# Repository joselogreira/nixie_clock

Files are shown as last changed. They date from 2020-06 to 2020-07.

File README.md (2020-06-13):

# **The Nixie Tube Clock** by [Nuvitron]

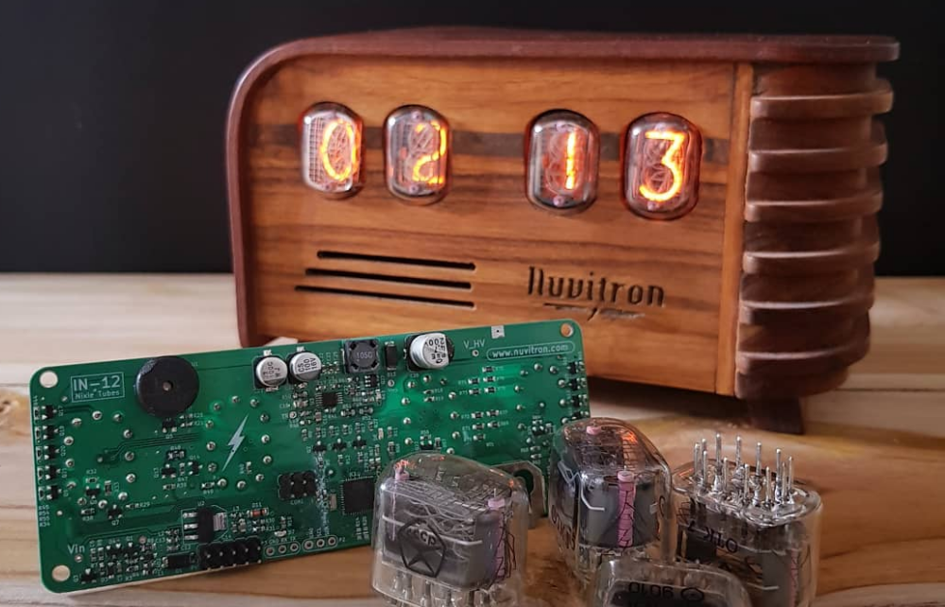
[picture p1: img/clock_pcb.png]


At Nuvitron, I led the electronics development of The Nixie Clock hardware included in some of their models. This repository starts from the production version of the clock circuit, and includes further improvements in the form of:

- Code refactoring
- Hardware tweaks (pending)

---

## Toolchain:

This project is based on an [ATmega324pb][324pb] MCU from Atmel (now Microchip). The standard AVR toolchain for Ubuntu Linux was used. No bootloader implemented. Not tested under Windows or Mac.

- [avr-gcc] for compiling and building.
- [avr-libc] for AVR libraries.
- [avrdude] for programming, using [usbasp] programmer or alternatively the official [AVR ISP MK2][mk2]

There're many guides on how to install and set-up the toolchain. [Here's one] of many guides available.

***Sidenote:*** The ATmega324pb MCU is NOT supported by default, neither by *AVRdude* nor by *avr-gcc*, thus, a few extra steps need to be performed in order to get this toolchain to work properly. It's just a matter of including some extra files in the proper locatios to fully support the MCU:
* **AVRdude**: it uses a configuration file that includes all MCUs recognized by the program, among other things. Mine is at `/etc/avrdude.conf`. Edit it (with *root* proviledges) and add an entry for the *ATmega324pb*. Use the *ATmega324pa* as an example, which inherits most of the properties from the ATmega324p. The signature for the 324pb is `1e 95 17`. Alternatively, I've added my `avrdude.conf` to the repo, [here][special].
* **avr-gcc**: A device specification file must be included. My path: `/usr/lib/gcc/avr/5.4.0/device-spec/`. The missing file is called `specs-atmega324pb` and I found it in a Windows installation of [Atmel Studio][astudio], the Atmel IDE for Windows. Within this file there's a couple of dependencies pointing to files in the avr-libc path.
* **avr-libc**: Three files are needed. Again, I found them in the Atmel Studio Windows installation path. My paths for these files are:
  * `/usr/lib/avr/include/avr/` must include the file `iom324pb.h`, which is the memory mapping for all MCU peripherals and special registers.
  * `/usr/lib/avr/lib/avr5/` must include `crtatmega324pb.o` and `libatmega324pb.a`.

***Sidenote 2:*** The latest version of Atmel Studio (7.0, at the time of this writting) doesn't include support for the *ATmega324pb* out-of-the-box. Instead, the user must install an additional package to fully support it. It's called *"Device Firmware Pack"*, and it's installed within Atmel Studio in the *"Device Package Manager"* window. Search for ATmega_DFP and install it. Mine was version `1.2.272`. Once installed, the previously mentioned Windows files can be found at:
  * `\<install-path>\Atmel\Studio\7.0\packs\atmel\ATmega_DFP\1.2.272\include\avr\iom324pb.h`
  * `\<install-path>\Atmel\Studio\7.0\packs\atmel\ATmega_DFP\1.2.272\gcc\dev\atmega324pb\avr5\crtatmega324pb.o` and `libatmega324pb.a`
  * `\<install-path>\Atmel\Studio\7.0\packs\atmel\ATmega_DFP\1.2.272\gcc\dev\atmega324pb\device-specs\specs-atmega324pb`

For the sake of completeness, these files are also included [here][special].

---

## Project Folders
- **src**: contains all the code files needed, including library files.
- **special**: contains all *"additional"* files to support the MCU.
- **img**: some images of the project.
- **docs**: GitHub [project page][ppage].
- **output**: not included in the repo. Automatically created once the Make recipe is executed.

---

## Hardware Characteristics:
- MCU: ATmega324pb 
- (pending)

---

## License

Released under the [MIT License][license] - 2020 Jose Logreira

[clock_pcb]: https://raw.githubusercontent.com/joselogreira/nixie_clock/master/img/clock_pcb.png "Nixie Clock Circuit"
[Nuvitron]: <https://nuvitron.com>
[avr-gcc]: <https://www.microchip.com/mplab/avr-support/avr-and-arm-toolchains-c-compilers>
[avr-libc]: <https://www.nongnu.org/avr-libc/user-manual/overview.html>
[avrdude]: <https://www.nongnu.org/avrdude/>
[usbasp]: <https://www.fischl.de/usbasp/>
[Here's one]: <http://maxembedded.com/2015/06/setting-up-avr-gcc-toolchain-on-linux-and-mac-os-x/>
[special]: /special/
[astudio]: https://www.microchip.com/mplab/avr-support/atmel-studio-7
[324pb]: http://ww1.microchip.com/downloads/en/DeviceDoc/40001908A.pdf
[mk2]: http://ww1.microchip.com/downloads/en/DeviceDoc/Atmel-42093-AVR-ISP-mkII_UserGuide.pdf
[license]: /LICENSE
[ppage]: https://joselogreira.github.io/nixie_clock/

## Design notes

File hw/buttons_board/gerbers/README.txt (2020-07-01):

Description of the compressed files:

PROJECT NAME: buttons_board
> THT components only
> Components in only top side of the PCB

Gerber files and description:

- buttons_board.drl: (Excellon) Descripción de las perforaciones de la tarjeta
- buttons_board-B.Cu.gbr: (Gerber) Máscara inferior de pistas de cobre
- buttons_board-B.Mask.gbr: (Gerber) Máscara inferior de puntos de soldadura de componentes 
- buttons_board-drl.rpt: (Texto Plano) Listado de diámetros de brocas a usar
- buttons_board-drl_map.gbr: (Gerber) Mapa de perforaciones en formato gerber
- buttons_board-Eco1.User.gbr: (Gerber) Capa de domentación para fabricación
- buttons_board-Edge.Cuts.gbr: (Gerber) Bordes de la PCB
- buttons_board-F.Silk.gbr: (Gerber) Máscara superior de componentes, Logo y leyendas

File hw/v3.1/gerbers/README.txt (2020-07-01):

Description of the compressed files:

PROJECT NAME: nixie_clock_3
> SMT and THT components 
> Components in both sides of the PCB

Gerber files and description:

- nixie_clock_3.drl: (Excellon) Description of the board drilling holes
- nixie_clock_3-B.Cu.gbr: (Gerber) Bottom mask of copper traces
- nixie_clock_3-B.Mask.gbr: (Gerber) Bottom mask of components solder paste layer
- nixie_clock_3-B.Silk.gbr: (Gerber) Bottom mask of components silkscreen and logos
- nixie_clock_3-drl.rpt: (Plain text) Drilling bit diameters list
- nixie_clock_3-drl_map.gbr: (Gerber) Map of drilling holes as gerber format
- nixie_clock_3-Eco1.User.gbr: (Gerber) Documentation layer for manufacturing
- nixie_clock_3-Edge.Cuts.gbr: (Gerber) PCB edges
- nixie_clock_3-F.Cu.gbr: (Gerber) Top mask of copper traces
- nixie_clock_3-F.Mask.gbr: (Gerber) Top mask of components solder paste layer
- nixie_clock_3-F.Silk.gbr: (Gerber) Top mask of components silkscreen and logos

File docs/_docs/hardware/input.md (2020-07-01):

---
title: Input protection
permalink: /docs/input/
---

__[PDF schematic](/nixie_clock/assets/pdf/nixie_clock_3.pdf "Schematic")__

The circuit is protected against four undesired situations:

* _Reverse polarity protection_
* _Overvoltage_
* _Undervoltage_
* _Inrush current_

The image below shows the power input circut section, that implements 3 of these four measures.

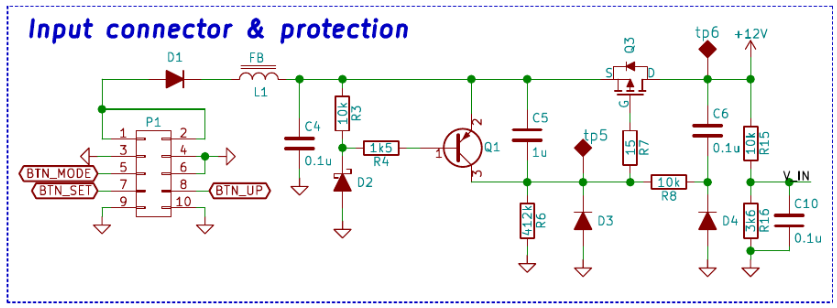
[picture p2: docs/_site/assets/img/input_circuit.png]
Input circuit


The connector P1 to the left receives power and button signals from a secondary PCB on the back of the clock that includes the 12V plug and three buttons. Both PCBs are connected via a 10-wire ribbon cable.

* ___Reverse polarity protection:___ This is the simplest. The diode `D1` protects against any backward current flow. The drawback is the diode voltage drop (close to 0.5V). If necessary, it can be avoided by using a MOSFET switch like [this one](https://circuitdigest.com/electronic-circuits/reverse-polarity-protection-circuit-diagram). But it wasn't necessary in this case.

* ___Overvoltage:___ `D2` is a Zener diode with zener voltage of 14V. When an input voltage above 14.5V (aprox.) is applied to the input, `D2` conducts current, forcing `Q1` into saturation (that is, Vce close to zero), thus, switching the P-channel MOSFET transistor `Q3` off. This way, overvoltage causes the whole circuit to be de-energized. Only the maximum voltage ratings of the input components limit the maximum input voltage, which can be up to 40V. Overvoltage protection is desired since some of the components of the circuit have a maximum voltage rating of 18V.

* ___Undervoltage:___ This one is not implemented by the input circuitry. There might be a discrete solution using zeners and transistors to implement undervoltage limits, but it was much easier to 
do in software. Basically, at start up, the MCU checks all system voltages. If there's an input voltage lower than nominal 12V, the boost converter won't be enabled. This way, the boost controller is protected from working with duty cicle very close to 1.

* ___Inrush current:___ Needed for two reasons:
	* The current spike produced in the connection process degrades the bulk capacitance in the circuit, and may produce MCU malfunction at start up.
	* The quality of the user's power adapter is unkwnown, and there's an alarmingly high amount of adapters without converter controller chips. This translates into power adapters not working, or producing big voltage sags in the connection moment, or outputting voltages different than 12V after connecting them. Thus, [Inrush Current Limitting](https://en.wikipedia.org/wiki/Inrush_current_limiter) (ICL) is a safety measure against weak power sources.

ICL is the most interesting, so it's explained below.

The goal is to switch on `Q3` slowly, in a controlled fashion, so that it remains in active mode (not in saturation) for a short period of time, such that it effectively acts as a resistor. This is achieved by slowly decreasing the Gate voltage (with respect to Source) using the RC  filter `C5` and `R6`. As soon as `Q3` reaches the threshold voltage, current starts flowing through the transistor and the voltage at `TP6` increases. `C6` and `R8` act as a feedback loop, so when voltage at `TP6` increases, current across `R6` also increases and _Vgs_ (source-gate voltage) gets regulated. The whole transient effect results in a very nice ramp voltage from zero to 12 volts at `TP6` (the +12V rail), lasting a some milliseconds. This is shown in the image below.

osciloscope capture

<ul>
	<li><strong style="color:gold">Yellow trace:</strong> Input voltage rail (from power adapter).</li>
	<li><strong style="color:aqua">Blue trace:</strong> MOSFET gate voltage (with respect to ground).</li>
	<li><strong style="color:purple">Purple trace:</strong> 12V rail (TP6).</li>
</ul>

`R15` and `R16` sample the input voltage to be read by the MCU.

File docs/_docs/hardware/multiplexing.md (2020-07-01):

---
title: Tubes' discrete multiplexing
permalink: /docs/multiplexing/
---

__[PDF schematic](/nixie_clock/assets/pdf/nixie_clock_3.pdf "Schematic")__

Multiplexing is mandatory. There's just not enough pins in the MCU to directly drive evey tube.

To multiplex tubes' anodes, [high side drivers](https://electronics.stackexchange.com/questions/188745/high-side-driver-and-low-side-driver) are needed. To multiplex tubes' digits (cathodes), low side drivers are needed.

At the time of sourcing the components, no integrated IC driver was found for 160V high side switching. It's just too much voltage, so a discrete solution was implemented using high voltage transistors. Every tube anode required a pair of NPN-PNP transistors. For the digits multiplexing, discrete high voltage transistors were used.

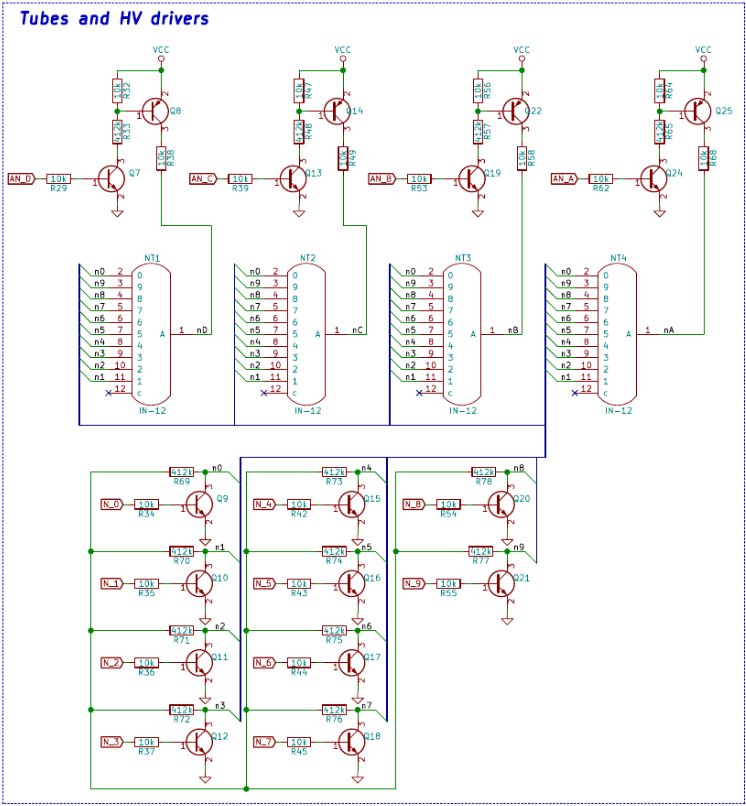
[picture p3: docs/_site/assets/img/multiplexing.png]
Tubes' multiplexing Tubes' Multiplexing


An interesting addition were the resistors `R69` to `R77`. They're all the same high value, and they all join each low side transistor's drain terminal (or cathode terminal) with a floating common node for all digits. Why is that? The concept was taken from the reference design below [found here](https://www.pinitech.com/retrofit/schematics.php).

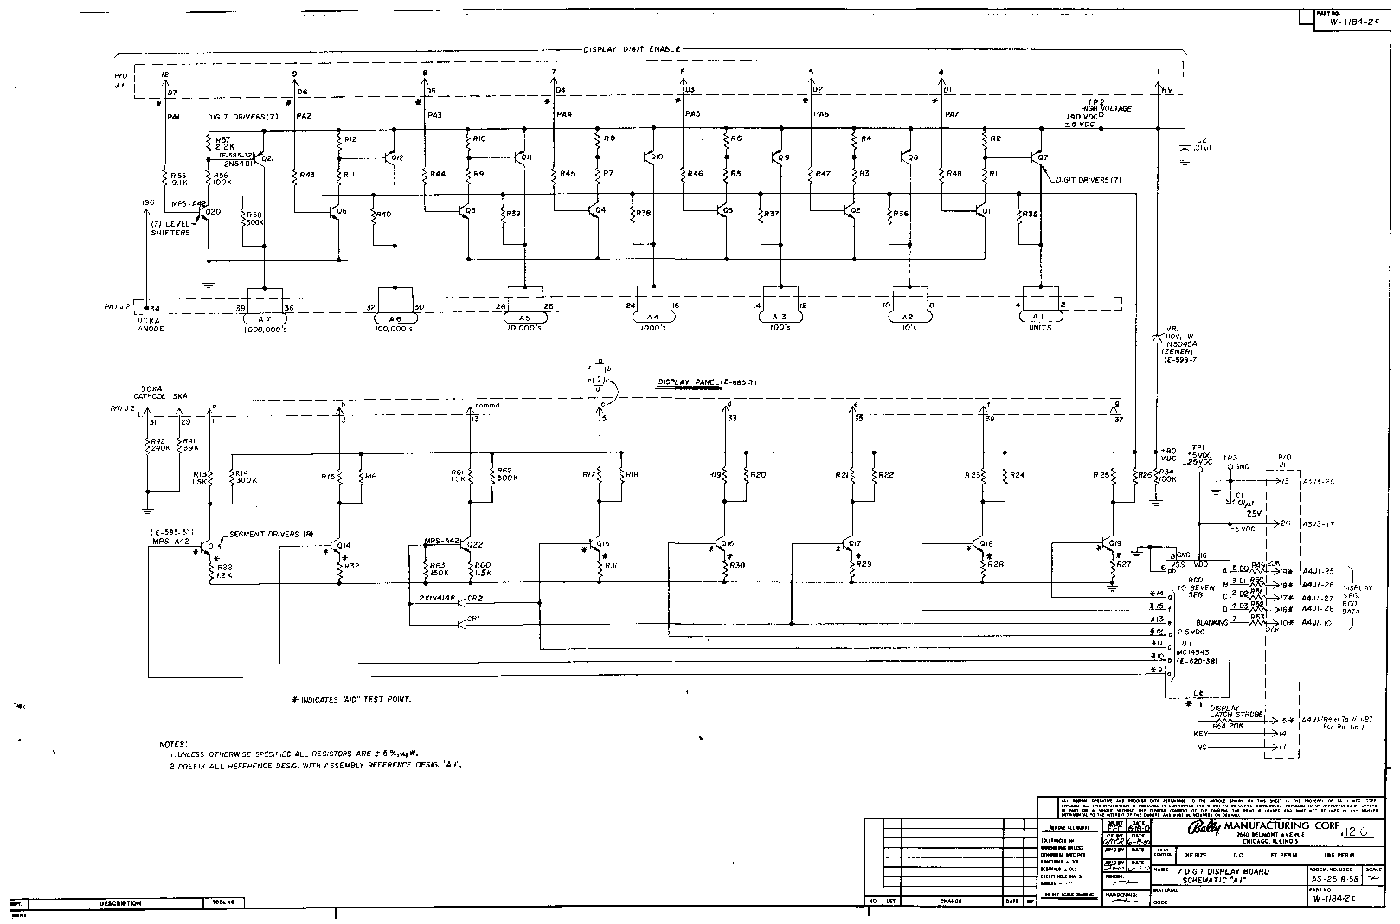
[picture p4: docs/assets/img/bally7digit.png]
bally7digit


Basically, __not all tubes' digits require the same voltage to glow__, thus, when multiplexing, it happens that one digit being addressed requires more anode-to-cathode voltage than others not being addressed, thus, the voltage applied to the one being addressed is enough to lightly make the one not being addressed glow, and the current flow goes throgh the low-side driver of the digit being addressed. This is because inside the tubes, no electrical isolation exists between the digits. This is the origin of the so-called ghosting effect in nixie tubes.

One solution is the one proposed: by tying all cathodes with high value resistors, only the addressed digit is fully ON, and all other cathodes are at a higher potential, that inhibits them from glowing. The solution is not perfect, but is simple and greatly reduces ghosting. Other solutions require more resistors, capacitors, zeners and the like, operating at high voltage, which requires way more space than what is available on the PCB (due to [clearance and creepage distances](https://www.smps.us/pcbtracespacing.html)).

## Timing

Each tube's anode is addressed for 5ms. During that time, the addressed tube's digit is ON for 1 to 5ms. It depends on the fade level. That way, individual fading levels can be applied to each tube. This is useful for implementing animations or transition effects.

Timing is completely controlled by ISRs. More on that, [here](/nixie_clock/docs/isr/).

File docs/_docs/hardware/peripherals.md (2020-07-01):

---
title: MCU peripherals
permalink: /docs/peripherals/
---

__[PDF schematic](/nixie_clock/assets/pdf/nixie_clock_3.pdf "Schematic")__

This is a list of the peripherals used:

* __GPIO__: including pin change interrupts
* __ADC__: to check system voltages.
* __EEPROM__: to save or read user configuration and testing results.
* __UART__: serial communication to communicate with PC
* __Timers__: events and tasks coordination. It includes RTC (using external quartz crystal) and LEDs' PWM generation.

Some of the miscellaneus elements around the MCU are shown below.

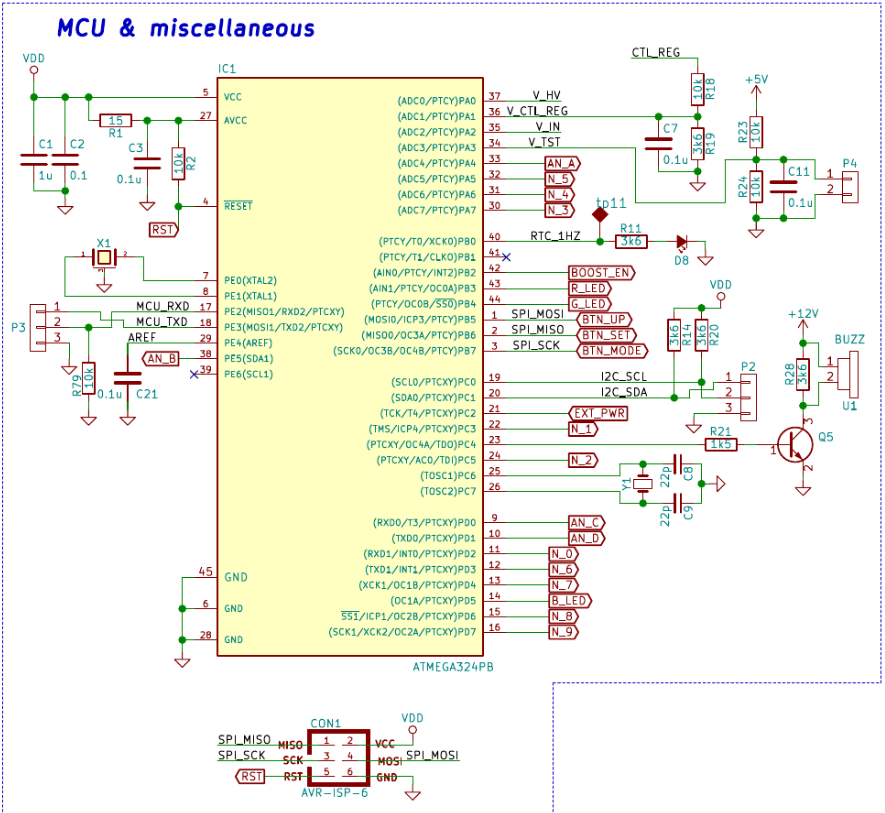
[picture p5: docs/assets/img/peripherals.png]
Peripherals Tubes' Multiplexing


The buzzer shown below is a piezoelectric one. Using a timer to generate 50% duty cycle PWM with variable frequency, different tones are generated.

Four RGB LEDs are mounted behind every tube. They are wired as two strings of LEDs. These are also controlled by PWM generated by timers with fixed frequency, but variable duty cycle.

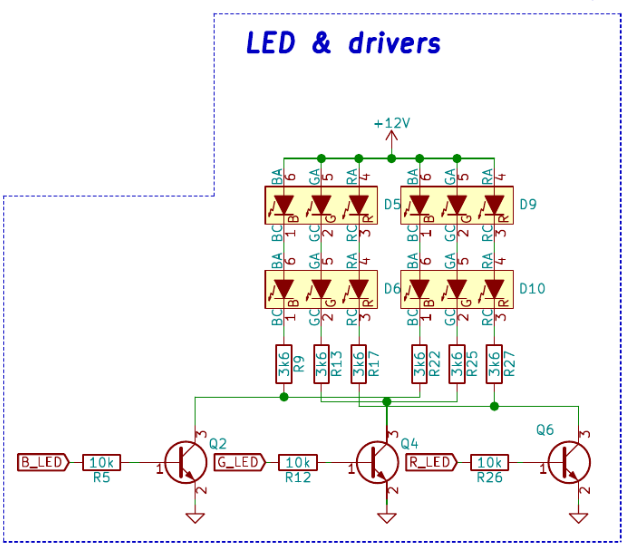
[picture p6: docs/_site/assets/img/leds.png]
LEDs strings


The I2C port was left available for any future addition or integration with I2C-based devices like temperature sensors, accelerometers, etc.

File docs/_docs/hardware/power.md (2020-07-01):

---
title: Voltages and power
permalink: /docs/power/
---

__[PDF schematic](/nixie_clock/assets/pdf/nixie_clock_3.pdf "Schematic")__

The 160V high voltage source for the Nixie tubes is a [boost converter](https://en.wikipedia.org/wiki/Boost_converter) based around the __[TPS40210](https://www.ti.com/product/TPS40210)__ from Texas Instruments. It handles all the boost control by itself, including overcurrent. The MCU enables or disables the converter operation.

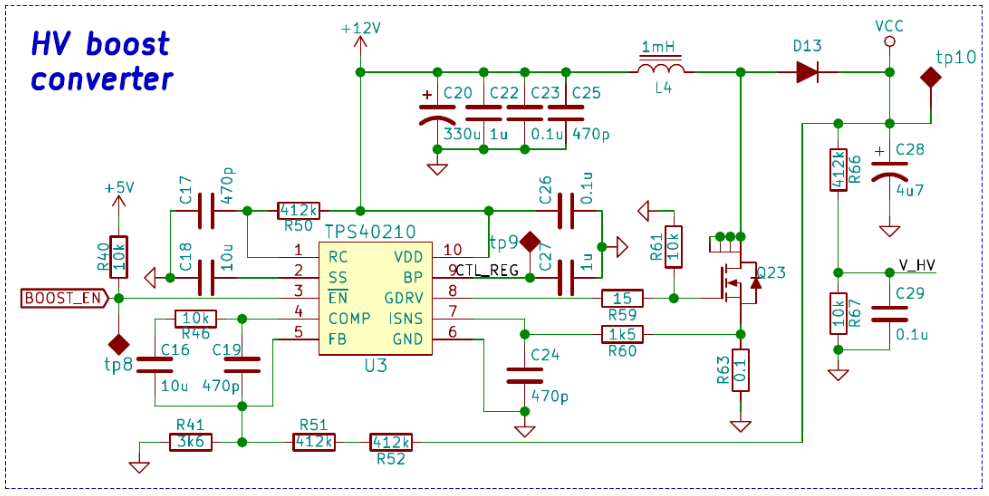
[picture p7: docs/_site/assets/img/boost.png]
Boost converter Boost Converter


The boost converter operates in Continuous Conduction Mode (CCM), its Duty Cycle is close to _0.95_, and switching frequency is around _100KHz_. It may seem an exreme operation case (due to its high voltage output), but keep in mind that individual digits glow with a current less than _2mA_ with full brightness. Besides, due to the [multiplexing](/nixie_clock/docs/multiplexing/) scheme, only one tube is active at a time. Thus, even when the voltage requirement is very high, the power requirement is very low.

The digital circuitry is powered with a simple linear regulator, but not directly from the regulator output: when external power is not present, the coin cell backup battery powers the MCU. This switching between these two sources is automatically performed using shottky diodes `D11` and `D12`. The presence of external power is sensed through `R30` and `R31`. That way, the MCU switches to [sleep mode](/nixie_clock/docs/sleep/) when no external power is sensed.

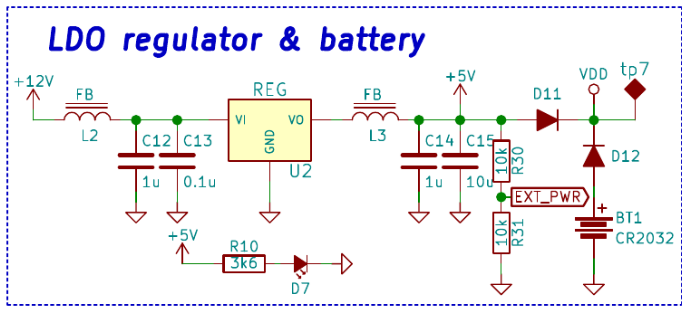
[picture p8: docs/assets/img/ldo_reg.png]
Linear regulator Linear Regulator and Battery


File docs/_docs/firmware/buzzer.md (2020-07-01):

---
title: Buzzer themes
permalink: /docs/buzzer/
---

Although the [piezoelectric buzzer](https://en.wikipedia.org/wiki/Buzzer) used is mechanically design for a resonant frequency of 4KHz, it can also produce tones at a wide range of frequencies. For the song themes implemented, more than 2 octaves were used to play all notes (from A6 to C9).

<iframe width="560" height="315" src="https://www.youtube.com/embed/HfNS7TEvCeo?start=131" frameborder="0" allow="accelerometer; autoplay; encrypted-media; gyroscope; picture-in-picture" allowfullscreen></iframe>

The mechanism for playng song themes in a non-blocking fashion is described below.

## Timer 

The 16-bit __TIMER 4__ is used. It's initialized and configured in `timers.c` with `timer_buzzer_init()`. Its behavior is to produce a PWM signal with 50% duty cycle by toggling an output pin on every compare match. That way, by changing the compare match value, the PWM frequency that drives the buzzer changes. `timer_buzzer_set()` is responsible for changing the buzzer frequency.

Base timer frequency is __2MHz__. Values for the compare match register can be derived for any note. It was chosen to use the [equal-tempered scale](https://pages.mtu.edu/~suits/notefreqs.html). These values are defined as macros inside `buzzer.c`:

```c
// TIMER COUNTER 3 MACROS (notes)
// All notes are divided by 8, since the operation frequency was changed from
// 16MHz to 2MHz
#define N_A6        4545/8  // 1760Hz
#define N_B6        4050/8  // 1975.53Hz
#define N_C7        3822/8  // 2093.00Hz
#define N_Db7       3608/8  // 2217.46Hz
//
// more notes
//
#define N_A8        1136/8  // 7040.00Hz
#define N_B8        1012/8  // 7902.13Hz
#define N_C9        956/8   // 8372.02Hz
#define N_SIL       0xFFFF  // Silence
```

## Tempo

On the other hand, there must be a mechanism to compute the duration of a musical note. This is achieved by using the system-wide __1ms__ time base. Thus, the note duration can now be expressed as a counter value, which translates to a time multiple of __1ms__. 

But, when dealing with sheet music the notes' duration is determined by the song's [tempo](https://en.wikipedia.org/wiki/Tempo) in combination with the [music symbol](https://en.wikipedia.org/wiki/List_of_musical_symbols) (I hope not to say some blasphemy for musicians). That way, a base tempo of __100__ (beats per minute) is chosen to determine the duration of notes. Any song with different tempo must take 100 bpm as a reference to make an equivalence for its own tempo. Notes' duration with Tempo of 100 are:

```c
// Music notes duration (reference tempo: 100)
#define SIXTEENTH_NOTE  (QUARTER_NOTE / 4)
#define TWELVETH_NOTE   (QUARTER_NOTE / 3)
#define EIGHTH_NOTE     (QUARTER_NOTE / 2)
#define SIXTH_NOTE      (TWELVETH_NOTE * 2)
#define QUARTER_NOTE    (60000 / 100)
#define HALF_NOTE       (QUARTER_NOTE * 2)
#define WHOLE_NOTE      (QUARTER_NOTE * 4)
```

## Song themes array

Putting both previous concepts together, any song based on tones can be expressed as an array of note-duration pairs. The [Star Wars theme](https://www.youtube.com/watch?v=lK25-we91L8) can now be represented as shown below. It has a tempo of __108__, so an adjustment must be made to the notes' duration in order to properly play the song.

```c
/*
* Melodies are stored as an array of note-duration structures. "note" field 
* determines the musical note (the PWM frequency of the buzzer), and "duration"
* determines how long the note is to be played.
*/
typedef struct {
    uint16_t note;
    uint16_t duration;
} note_s;

static const note_s star_wars_theme[] PROGMEM = {
    {N_SIL, QUARTER_NOTE},
    {N_C7, TWELVETH_NOTE},
    {N_C7, TWELVETH_NOTE},
    {N_C7, TWELVETH_NOTE},
    {N_F7, HALF_NOTE},
    {N_C8, HALF_NOTE},
    {N_B7, TWELVETH_NOTE},
    {N_A7, TWELVETH_NOTE},
    {N_G7, TWELVETH_NOTE},
    {N_F8, HALF_NOTE},
    {N_C8, QUARTER_NOTE},
    {N_B7, TWELVETH_NOTE},
    {N_A7, TWELVETH_NOTE},
    {N_G7, TWELVETH_NOTE},
    {N_F8, HALF_NOTE},
    {N_C8, QUARTER_NOTE},
    {N_B7, TWELVETH_NOTE},
    {N_A7, TWELVETH_NOTE},
    {N_B7, TWELVETH_NOTE},
    {N_G7, HALF_NOTE},
};
```

## Playing the songs

Much like the [buttons debouncing routine](/nixie_clock/docs/debounce/), the `buzzer_music()` function works the same way. It relies on a __1ms__ loop period, so that the function may be called once per millisecond. Its internal variables need to be `static` to preserve the context between subsequent executions.

First time the function is called, an initialization step occurs, which initializes some variables and adjusts notes' duration, storing the new value in a dynamically created vector.

```c
duration_p = (uint16_t *)calloc(size, sizeof(uint16_t));

// calculate proper notes' duration and store the result in vector
for(uint8_t i = 0; i < size; i++)
    duration_p[i] = note_duration(pgm_read_word(&theme_p[i].duration), tempo);

//
// a few lines  below:
/*===========================================================================*/
/*
*   Base tempo is 100 (100 bits per minute). 
*/
static uint16_t note_duration(uint16_t counts, uint8_t tempo)
{
    float f_tempo = (float) tempo;
    float f_counts = (float) counts;
    float x = (100.0 / f_tempo) * f_counts;

    return (uint16_t) x;
}
```

After that, a couple of nested counters `count` and `n` iterate through the entire song theme array, setting the buzzer timer with the corresponding note frequency, and letting it play for the corresponding note duration.

```c
if(count >= duration_p[n]){
    n++;
    if(pgm_read_word(&theme_p[n].note) != N_SIL)
        timer_buzzer_set(ENABLE, pgm_read_word(&theme_p[n].note));
    else
        timer_buzzer_set(DISABLE, pgm_read_word(&theme_p[n].note));
    count = 0;
}
```

Once the cycle reaches the end of the array, it disables the buzzer and outputs a `TRUE` value to indicate the end of the song.

```c
if(n >= size){
    timer_buzzer_set(DISABLE, N_C8);
    free((void *)duration_p);
    theme_p = NULL;
    duration_p = NULL;
    intro = TRUE;
    out = TRUE;
}
```

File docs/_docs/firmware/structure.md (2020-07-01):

---
title: Overall Structure
permalink: /docs/structure/
---

I'll start describing the core functionality and then describing some of the details. Let's see the `main()` function.

### Main loop

It's best to first describe the system from an abstract perspective, instead of start describing the codebase line by line.

<iframe width="560" height="315" src="https://www.youtube.com/embed/HfNS7TEvCeo" frameborder="0" allow="accelerometer; autoplay; encrypted-media; gyroscope; picture-in-picture" allowfullscreen></iframe>

The system functions are based on the display state, that is, on what's actually being displayed. Of course, each tube has limited amount of characters (namely, 0 to 9), so in order to display different information, the RGB LEDs come in handy to help understan what's actually being displayed. According to the state, the buttons have different behavior. These system states are:

* _Display time:_ Shows the actual time of the day. This is the default system state
* _Display menu:_ Shows the configuration menu for all options of the clock
* _Set time:_ Changes the actual minutes and hours
* _Set hour mode:_ Toggles between 12h and 24h
* _Set alarm:_ Changes the alarm time
* _Set alarm active:_ Enables/Disables the alarm
* _Set alarm theme:_ Changes the alarm song theme
* _Alarm triggered:_ The alarm event is triggered. Alarm song is playing.
* _Set transitions:_ Clock includes animations. These are configures in this state.

Some of these states include sub-states to implement some specific behavior or animation, or even to perform a visual test on all the tubes. They will be covered in their respective section.

The `main()` function includes an infinite loop in the form of a `switch() case:` structure. Each display state lies within one of the `case` statements in the form of a function call. When the _Display time_ state (just as example) is to be displayed (that is, active), the program execution jumps to the _Display time_ function, and remains inside the function for as long as the clock displays the time. Once the user switches to some other state, the function call returns and changes to the appropiate new function call. This is shown in the image below.

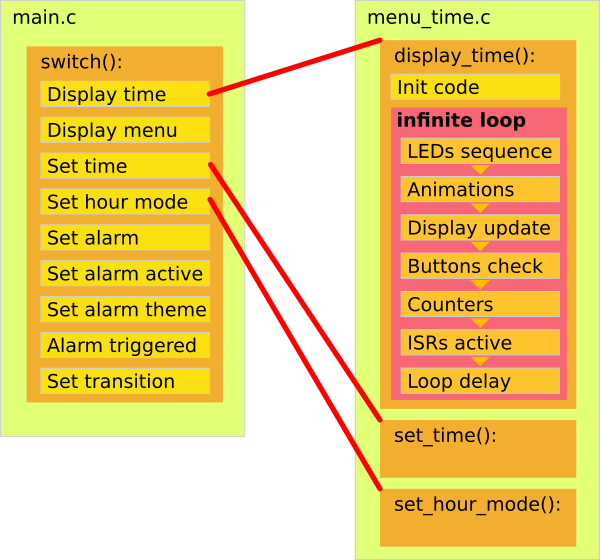
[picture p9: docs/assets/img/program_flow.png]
Program Flow Typical program flow


This systems is event-based, meaning that program execution is determined by one of two things:
* _User input_ in the form of buttons pushed.
* _Software events_ in the form of timers or counters that determine a certain action or behavior.
This model implies a few important things:
* Whatever the current system state is, the MCU must constantly check if events have happened, and be flexible enough to break the current program flow and _"switch context"_ to a different system state. __NOTE:__ This situation demands some code repetition between all system states to handle events. Although it is possible to avoid code repetition, the resulting code is harder to understand and maintain. Further details will be given below.

* Many of the events require a time base, thus, a __1ms__ period timebase is chosen, and configured in one of the ISRs.

### System states' timed loop

Inside of every system state function, there's an infinite loop inside of which the actions to be performed are synchronized with timers, external events or internal counters. Almost all system states have the same structure, with the exception being `SYSTEM_SLEEP`, `SYSTEM_RESET` and `PRODUCTION_TEST`.

The general structure follows the pattern below:

```c
void system_state_handler(state_t *state)
{
	// initialize variables

	/* INFINITE LOOP */
	while(TRUE){

		/*
		*	DISPLAY TRANSITIOS
		*	Animations and transitions depend on the systeme state
		*/
		
		/* 
		* BUTTONS check: Buttons are detected using an ISR which sets btnXYZ
	    * structure flags. Once set, the rest of the detection and debounce routine is
	    * handled within buttons_check(), based on the 1ms execution period of
	    * the main infinite loop
		*/
		if(btnX.query) buttons_check(&btnX);
	    if(btnY.query) buttons_check(&btnY);
	    if(btnZ.query) buttons_check(&btnZ);

	    /*
	    * BUTTONS actions:
		* - executed according to the buttons state flags
		*
		* If X pressed, then ...
		* If Y pressed, then ...
		* If Z pressed, then ...
		*/

		/*
		* 	GENERAL FUNCTION COUNTER
		*/
		count++;
		// some code to handle counter

		/* 
		* LOOP DELAY AND INTERRUPT ENABLE TIME --------------------------------
		* All interrupts are served within the sei()-cli() block. This is to 
		* avoid the extra care required for arbitrarily triggered ISRs and the 
		* use of atomic operations. "loop" flag is set every 1ms by a timer
		* whose ISR is enabled to produce interrupts every 1ms
		*/
		sei();
		// Wait for the next ms.
		while(!loop);
		loop = FALSE;
		cli();
		// If system state changed, exit fuction.
		if(*state != SET_ALARM_ACTIVE)
			break;

	}	/* END INFINITE LOOP */
}

```

Key points:

* __ISRs are NOT enabled all the time__. They're only enabled once the whole loop tasks get executed. Loop period is 1ms, and all the loop tasks are executed in much less than 1ms. Thus, ISRs are enabled for all the remaining time.
* The External Interrupt for the buttons sets the `btnXYZ.query` flag. Once set, it means that the `buttons_check()` routine gets executed. But this is NOT a blocking routine, instead, buttons' states are evaluated after multiple runs of the same routine over the same button. More explanations [here](/nixie_clock/docs/debounce/index.html).
* Most system states require some sort of internal counter to synchronize actions. Limit counter values are handled individually in every system state.

### Global structures

To better organize data across all modules, a few global data structures are created related to: time data, alarm data, display data and buttons data. Data structures are first prototyped using `typedef` and exposed globally using `extern` in the respective `.h` header file, and defined in the respective `.c` file.

> __NOTE:__ no bit fields are used.

* ___Time data___: Includes data related to current time, time format, and an important flag that signals whether current time has been updated or not (updates happen every second). Files involved: `menu_time.c` and `menu_time.h`:

```c
/* menu_time.h */
typedef volatile struct {
	uint8_t	sec;			// seconds
	uint8_t min;			// minutes
	uint8_t hour;			// hours
	uint8_t s_units;		// BCD seconds' units
	uint8_t s_tens;			// BCD seconds' tens
	uint8_t m_units;		// BCD minutes' units
	uint8_t m_tens;			// BCD minutes' tens
	uint8_t h_units;		// BCD hours' units
	uint8_t h_tens;			// BCD hours' tens
	uint8_t update;			// flag. 1Hz update?
	uint8_t hour_mode;		// 12/24h 
	uint8_t day_period;		// AM/PM
} time_s;

extern time_s time;

/* menu_time.c */
time_s time;
```

* ___Alarm data___: Includes data related to alarm configuration, and an important flag that signals whether alarm is enabled or not. Files involved: `menu_alarm.c` and `menu_alarm.h`:

```c
/* menu_alarm.h */
typedef struct {
	uint8_t	sec;			// seconds
	uint8_t min;			// minutes
	uint8_t hour;			// hours
	uint8_t s_units;		// BCD seconds' units
	uint8_t s_tens;			// BCD seconds' tens
	uint8_t m_units;		// BCD minutes' units
	uint8_t m_tens;			// BCD minutes' tens
	uint8_t h_units;		// BCD hours' units
	uint8_t h_tens;			// BCD hours' tens
	uint8_t hour_mode;		// 12/24h 
	uint8_t day_period;		// AM/PM
	uint8_t active;			// flag. Alarm ON?
	volatile uint8_t triggered;	// flag. Alarm MATCH?
	uint8_t theme;			// Alarm melody
} alarm_s;

extern alarm_s alarm;

/* menu_alarm.c */
alarm_s alarm;
```

* ___Display data___: Includes data related to current display contents, fading level and display mode (used to differentiate transitions or animations). Files involved: `timers.c` and `timers.h`:

```c
/* timers.h */
typedef volatile struct {
    uint8_t mode;
    uint8_t d1;
    uint8_t d2;
    uint8_t d3;
    uint8_t d4;
    uint8_t set;
    uint8_t fade_level[4];
} display_s;

extern display_s display;

/* timers.c */
display_s display;
```

* ___Buttons data___: Includes data related to current buttons state. Operations upon this structure occur only during the buttons debounce routine, and its state gets polled to check for buttons activity. Further explanation on debounce routine can be found [here](/nixie_clock/docs/debounce/index.html). Files involved: `external_interrupt.c` and `external_interrupt.h`:

```c
/* external_interrupt.h */
typedef struct {
	volatile uint8_t query;	// flag; query button state
	uint8_t action;			// flag; button action activated
	uint8_t lock;			// flag; button locked
	uint8_t state;			// button state: IDLE, PUSHED, RELEASED
	uint16_t count;			// time counter
	uint8_t delay1;			// flag; delay 1 elapsed
	uint8_t delay2;			// flag; delay 2 elapsed
	uint8_t delay3;			// flag; delay 3 elapsed
	uint8_t (*check)();		// function pointer to a state check handler
} btn_s;

extern btn_s btnX, btnY, btnZ;

/* external_interrupt.c */
btn_s btnX, btnY, btnZ;;
```

### Macros and constants

Many modules require their own set of private macros (either for configuration or for constants definition). Some others require to expose their macros to other modules. The private macros are defined in the respective modules' `.c` file, and those shared with other modues are declared in the `.h` file. Appart from those, there're some "generic" macros that are declared in the `config.h` file, which is included in most of the modules. 

This file also includes a couple of `extern` variables declared in `main.c` required to be accessible by other modules. 

### Interrupt Service Routines

All the ISR handler functions are defined at the end of `main.c`. These are:

* `ISR(TIMER2_OVF_vect){}`: Used as Real Time Counter. It's an asynchronous peripheral that has its own clock source from the 32,768KHz external crystal.
* `ISR(TIMER3_COMPA_vect){}`: Used as general purpose timer. It has a 1ms period and is responsible for:
	* Nixie tubes [multiplexing](/nixie_clock/docs/multiplexing/index.html)
	* System states' loop timed execution.
* `ISR(PCINT1_vect){}`: Pin change interrupt. Used to detect the buttons press.
* `ISR(PCINT2_vect){}`: Pin change interrupt. Used to detect the external power removal or connection.

Further information can be found [here](/nixie_clock/docs/isr/index.html).

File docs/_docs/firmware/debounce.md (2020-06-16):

---
title: Debounce routine
permalink: /docs/debounce/
---

Debouncing has the objective of filtering the buttons' input signal to detect the relevant button actions and discard all unwanted bouncing to prevent undesired behavior.

Bouncing button signals can vary from a couple milliseconds (a good quality button) to a couple tens of milliseconds and beyond (bad quality buttons). Bouncing time is also affected by the pressure exerted on the button and button aging. Thus, a method based on polling button signals for fixed amounts of time is not reliable enough.

Hardware design techniques can be implemented to alleviate this problem such as the use of [RC filters][rc] or even the addition of [Schmitt triggers][st]. None of these techniques have been used since the algorithm implemented has proven to be reliable enough, without significant impact on code execution time.

[rc]: https://electronics.stackexchange.com/questions/332074/schmitt-trigger-in-button-debouncer
[st]: http://hades.mech.northwestern.edu/index.php/Switch_Debouncing

### Debounce routine is NON-blocking

The `buttons_check()` debounce routine is defined inside [`util.c`](https://github.com/joselogreira/nixie_clock/blob/master/src/util.c).

It relies on the fact that the loop period is __1ms__. Once the `btnXYZ.query` flag is set by the ISR, this routine is executed once every millisecond as part of the loop tasks. It does poll the button state (by executing `(btn->check)()`) but never stops to wait for a certain time to ellapse. The buttons data structure is shown below (defined in `external_interrupt.h`).

```c
typedef struct {
    volatile uint8_t query; // flag; query button state
    uint8_t action;         // flag; button action activated
    uint8_t lock;           // flag; button locked
    uint8_t state;          // button state: IDLE, PUSHED, RELEASED
    uint16_t count;         // time counter
    uint8_t delay1;         // flag; delay 1 elapsed
    uint8_t delay2;         // flag; delay 2 elapsed
    uint8_t delay3;         // flag; delay 3 elapsed
    uint8_t (*check)();     // function pointer to a state check handler
} btn_s;
```

There're 3 button structures: one for every button. Since they are global, they preserve the current button state at each `buttons_check()` execution. 

There're three button states described as follows:

### `BTN_IDLE`:

This is the initial state. Once the button is pressed, the way to confirm that is trully pressed is by polling the pin state once every `buttons_check()` execution. If the button is effectively pressed, increase a counter. If not, decrease it.

```c
if(!(btn->check)()) btn->count++;
else if(btn->count > 0) btn->count--;
```

If the counter reaches the amount determined by the `BTN_DTCT_TIME` macro (7 times is OK), the button is assumed to be effectively pressed, the buzzer is enabled and it advances to the next state. If not, then it is kept in idle state.

```c
if(btn->count == BTN_DTCT_TIME){
    btn->action = TRUE;
    btn->lock = TRUE;
    btn->state = BTN_PUSHED;
    btn->count = 0;
    buzzer_set(ENABLE);
} else if(btn->count == 0){
    btn->action = FALSE;
    btn->lock = FALSE;
    btn->query = FALSE;
}
```

### `BTN_PUSHED`:

The routine keeps polling the button state and increasing a counter. Depending on the value of the counter, some flags are set. If the button is detected to be released, the state immediately chages to `BTN_RELEASED`. 

```c
if(!(btn->check)()){
    btn->count++;   
} else {
    btn->count = 0;
    btn->state = BTN_RELEASED;
}
if(btn->count == BTN_BEEP_TIME) buzzer_set(DISABLE);
if(btn->count == BTN_DLY1_TIME) btn->delay1 = TRUE;
if((btn->delay1) && (!(btn->count % BTN_DLY2_TIME))) btn->delay2 = TRUE;
if(btn->count >= BTN_DLY3_TIME) btn->delay3 = TRUE;
```

The buzzer beep was enabled when the button was detected to be pressed, and is disabled once `BTN_BEEP_TIME` milliseconds have elapsed. This accounts for a nice short _beep_ sound when any button is pressed.

There're 3 different delay time macros used for different purposes:

```c
#define BTN_DLY1_TIME   300     // time for delay 1
#define BTN_DLY2_TIME   65      // time for delay 2
#define BTN_DLY3_TIME   2000    // time for delay 3
```

* ___Delay 1___ and ___Delay 2___ resemble the times implemented in any key of a keyboard: once a key is pressed, the character is printed on the screen immediately. If the key remains pressed, nothing happens for about 500ms after which the key gets repeatedly printed on the screen, not with a period of 500ms but with a period much shorter (around 50ms). This is used on the clock for fast increment of digits (hours or minutes) when it's being configured.
* ___Delay 3___ is a _"long press"_ flag, which is set when the button press lasts for about 2000ms. Used in the clock to represent a ___"return"___ action when navigating through the clock menus.

### `BTN_RELEASED`:

The routine keeps polling the button state, this time looking for the button to be released (input HIGH) and increases a counter. The button must remain in active HIGH state (not pressed) for a time determined by the `BTN_LOCK_TIME` macro. Any further button detection or action is blocked unless the button remains released for that period of time, after which the button goes back to idle state.

```c
if((btn->check)())
    btn->count++;
if(btn->count == BTN_LOCK_TIME){
    btn->query = FALSE;
    btn->action = FALSE;
    btn->lock = FALSE;
    btn->state = BTN_IDLE;
    btn->count = 0;
    btn->delay1 = FALSE;
    btn->delay2 = FALSE;
    btn->delay3 = FALSE;
    buzzer_set(DISABLE);
}
```

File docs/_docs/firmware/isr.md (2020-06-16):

---
title: ISR and multiplexing
permalink: /docs/isr/
---

There're 4 Interrupt Service Routines in the systems. 2 related to timers and 2 related to digital pins state change. Each of them is configured and enabled during their respective peripheral initialization routine.

## Real Time Clock

A distinctive feature of this project is the implementation of the RTC using one of the MCU timer peripherals (__TIMER 2__). This way, code complexity is reduced since no communication with an external RTC is required, and the ability to keep track of time when there's no external power is preserved, since the backup coin cell battery powers the MCU just to allow the internal RTC peripheral to work. Further explanation about it can be found [here](/nixie_clock/docs/sleep/).

Timer 2 works asynchronously: it has its own 32,768KHz low power watch crystal oscillator. Interrupts are generated once every second. 

The handler updates the `time` structure with new values, taking into account the period of day (AM/PM), and time format (12h/24h):

```c
time.sec++;
if(time.sec == 60){
    time.sec = 0;
    time.min++;
    if(time.min == 60){
        time.min = 0;
        time.hour++;

        // more code
    }
}
```

Also updates the BCD values of the digits to be displayed by the tubes:

```c
time.s_tens = time.sec / 10;
time.s_units = time.sec % 10;
time.m_tens = time.min / 10;
time.m_units = time.min % 10;
time.h_tens = time.hour / 10;
time.h_units = time.hour % 10;
```

If the alarm is `ENABLE`, it checks for a match:

```c
if(alarm.active){
    if(alarm.hour == time.hour){
        if(alarm.min == time.min){
            if(alarm.sec == time.sec){
                if(alarm.day_period == time.day_period){
                    match = TRUE;
                    alarm.triggered = TRUE;
                }
            }
        }
    }
}
```

And finally, if the clock is running with external power applied (12V adapter), it toggles an onboard LED and sends via the serial port (UART peripheral), a string with the current time in format `hh:mm:ss`:

```c
if(EXT_PWR) {
    RTC_SIGNAL_TOGGLE();
    char string[9];

    /* string construction */

    uart_send_string(string);
    uart_send_string("\n\r");
} else {
    RTC_SIGNAL_SET(LOW);
}   
```

When no external power is applied, the RTC is the only peripheral that remains awake keeping track of time. Every second the ISR awakens the MCU to process the time update and goes back to sleep again.

## General timer counter

Uses __TIMER 3__. This timer generates interrupts every __1ms__. It has two main functions:

* This is the one responsible for the system states' timed loop execution by setting the `loop = TRUE;` flag.

* It controls the Nixies' multiplexing and fading scheme. Further explanation found [here](/nixie_clock/docs/multiplexing/). Tubes' anodes are updated once every 5ms (thus, overall refresh rate is 50Hz for all four tubes), and tubes' cathodes are updated once every 1ms (same as the timer period), the latter being the one responsible for the fading effect used in some animations. 

Using internal counters, once 5ms have elapsed, switch to the next tube:

```c
// multiplex tubes' anode every 5ms. Independent of fading level
if(!(cnt % 5)){
    // change tube selection
    n_tube++;
    if(n_tube >= 4) n_tube = 0;
    // enable tube anode
    set_tube(n_tube);
}
```

`n_fade` is also a counter (from 1 to 5) synced with the tube that's currently being displayed. Since every tube's anode is active for a period of 5ms, fading is achieved by varying the cathode's active time: 0ms is fully OFF, 5ms if fully ON. Values in between give intermediate brightness levels. Since each tube may have different brightness (or fade) levels, individual values for each tube are stored within the `display.fade_level[]` structure member.

```c
if(n_fade <= display.fade_level[n_tube]){
    if(n_tube == TUBE_A) set_digit(display.d1);
    else if(n_tube == TUBE_B) set_digit(display.d2);
    else if(n_tube == TUBE_C) set_digit(display.d3);
    else if(n_tube == TUBE_D) set_digit(display.d4);
} else {
    set_digit(BLANK);
}
```

## Buttons interrupts

Buttons' inputs to the MCU are pulled HIGH with internal pull-up resistors. When pressed, the input is pulled low. The interrupt handler is triggered with any edge detected (rising or falling edge). Thus, the filter for _falling edge_ must be filtered inside the handler by checkig whether the actual input value is low. If so, then the `btnXYZ.query` flag gets set:

```c
if((!(btnX.check)()) && (!(btnX.lock))){
    btnX.query = TRUE;
} else if((!(btnY.check)()) && (!(btnY.lock))){
    btnY.query = TRUE;
} else if((!(btnZ.check)()) && (!(btnZ.lock))){
    btnZ.query = TRUE;
}
```

The `btnXYZ.lock` flag is used to implement a _"dead time"_ when the button is released, so that program execution is able to ignore button actions for a period of time. This also makes part of the [debounce](/nixie_clock/docs/debounce/) routine implemented.

## External power interrupt {#external}

There's a digital input pin in the MCU that senses the presence of external power (12V adapter). When the external power is removed, the system must immediately go to sleep while allowing the RTC to work. This ISR handles this case:

```c
if(!EXT_PWR){
    // Boost is automatically powered off (12V removed)
    RTC_SIGNAL_SET(LOW);          // Dont use RTC LED
    system_state = SYSTEM_SLEEP;  // GO TO SLEEP !!!
}
```

It disables the onboard debug LED and overrides the `system_state` variable to put it to sleep within the next millisecond.

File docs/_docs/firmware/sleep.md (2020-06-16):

---
title: Sleep modes
permalink: /docs/sleep/
---

The reason for the sleep modes is better understood by looking at the MCU [power sources](/nixie_clock/docs/power/)). 

When the external power adapter is plugged in, the MCU is fully awake and all peripherals are working non-stop. When the external power is removed, the clock needs a mechanism to still keep track of the time, but of course minimize as much as possible the power consumption to avoid draining the coin cell battery too fast.

A third situation needs to be considered: the decission of not using an exteral RTC comes with a tradeoff: 

* Typical RTC chips have super low power consumption. They can keep the time for months and even years without battery replacement. 
* ATmega324pb is a chip optimised for low power consumption, but it can't reach the levels of independent RTCs. Thus, based on testing, it can only keep time for days and weeks, but not for months.

So, there's a problem during circuit testing, assembly, packaging and shipping: if the time between battery insertion to the circuit and customer delivery is greater than weeks, then the coin cell battery will be completely drained by then.

Shipping the battery sepparately is legally and logistically much more complicated, and asking the customer to open up the clock and instert the battery is just not acceptable. Thus, a third power management case must be considered: that in which the coin cell battery is inserted, but since the power adapter is NOT detected, the MCU must go to _deep sleep_ mode, disabling the RTC from keeping time until the customer receives the product and plugs it in for the first time. That way, battery life is preserved for much longer.

Each situation is covered separately:

### External power removal:

The MCU is assumed to opperate in any of the active sytem states. The series of steps is described below:

1. Power adapter disconnect triggers the [external power Pin Change Interrupt flag](/nixie_clock/docs/isr/#external). The CPU will finish whatever is currently doing in any system state loop and jump to the ISR handler within 1ms.

1. ISR handler checks if power is effectively removed, disables debug LED and overrides current system state to force program flow to jump back to _main loop_, and start executing `go_to_sleep()` system state function.
```c
ISR(PCINT2_vect)
{
    if(!EXT_PWR){
        // Boost is automatically powered off (12V removed)
        RTC_SIGNAL_SET(LOW);          // Dont use RTC LED
        system_state = SYSTEM_SLEEP;  // GO TO SLEEP !!!
    }
}
```

1. `sleep_mode` variable passed to `go_to_sleep()` is one of two values: `RTC_DISABLE` or `RTC_ENABLE` (default). This determines whether the time keeping function (the RTC) remains active or not.

1. A sequence of steps is performed to disable all peripherals one by one, including buttons interrupts. When the sleep cause is the external power that was removed, the RTC remains active. `ports_power_save(ENABLE)` configures input/output ports to avoid wasting unnecesary current.
```c
void peripherals_disable(volatile uint8_t mode)
{
	adc_set(DISABLE);
	uart_set(DISABLE);
	buzzer_set(DISABLE);
	timer_leds_set(DISABLE, 0, 0, 0);
	timer_base_set(DISABLE);
	buttons_set(DISABLE);
	// Disable RTC only if entering POWER DOWN
	if(mode == RTC_DISABLE)
		timer_rtc_set(DISABLE);
	ports_power_save(DISABLE);
}
```

1. Selects the right __sleep mode__. `SLEEP_MODE_PWR_DOWN` is the deepest sleep mode. `SLEEP_MODE_PWR_SAVE` keeps the RTC running. Then, go to sleep. Program execution is halted at this point. The only interrupt sources (wake up sources) enabled are RTC interrupts (to update time) and external power reconnection.
```c
if(mode == RTC_DISABLE)
	set_sleep_mode(SLEEP_MODE_PWR_DOWN);	// Select POWER_DOWN sleep
else if(mode == RTC_ENABLE)
	set_sleep_mode(SLEEP_MODE_PWR_SAVE);	// Select POWER_SAVE sleep
sleep_enable();						// Enable Sleep Mode 
sleep_bod_disable();				// Disable BOD when sleep 
sei();
sleep_cpu();
```

1. When the CPU wakes up, the first thing it does is to service the ISR call. Then, code execution return to the point right after where it went to sleep. Then it checks for the presence of external power. If present, enables all system peripherlas, performs some system checks and resumes normal execution. If not, goes back to sleep again.
```c
if(EXT_PWR) {
	step = ENABLE_SYSTEM;
	mode = RTC_ENABLE;
} else {
	step = SLEEP_CPU;
}
```

1. Two system checks are performed before resuming normal execution: `adc_voltages_test()`, which checks normal system voltage levels, and `alarm.triggered` flag, which might have been set during sleep mode (given the alarm was enabled). After that, program execution is resumed as usual.
```c
// check system voltages
_delay_ms(2000);
if(!adc_voltages_test()){
    system_reset = TRUE;
    *state = SYSTEM_RESET;				    
} else {
	if(alarm.triggered) *state = ALARM_TRIGGERED;
	else *state = SYSTEM_INTRO;
}
```

### Intentional system reset:

A general system reset can be enforced. It places the system in deep sleep mode (`SLEEP_MODE_PWR_DOWN`) which halts the RTC time keeping function. This is useful once the clock has been tested, the coin cell battery has been inserted, and it is desired to avoid the system from keeping time.

1. Once the clock is in the normal `DISPLAY_TIME` system state, all three buttons should be pressed at the same time for 2 seconds. This forces a system state override where the program execution will jump to `SYSTEM_RESET` and will halt the RTC peripheral.
```c
// IF ALL THREE BUTTONS PRESSED DURING DELAY3, RESET SYSTEM AND GO TO SLEEP
if((btnX.action) && (btnX.delay3) && (btnY.action) && (btnY.delay3) && (btnZ.action) && (btnZ.delay3)){
	btnX.action = FALSE;
	btnY.action = FALSE;
	btnZ.action = FALSE;
	display.set = OFF;
	system_reset = TRUE;
	*state = SYSTEM_RESET;
}
```

1. Once the program flow reaches `go_to_sleep()`, the sequence of events is exactly as described above, with the sole exception that now the sleep mode flag is set to `RTC_DISABLE`, and no RTC will be active. This way, the only wake up source will be the external power reconnection.

### Coin cell battery insertion:

If the coin cell battery is inserted in the circuit before it gets energized by the external power adapter, the MCU will start code execution as usual, so one of the firts tasks it must perform is to check for the existence of external power. Otherwise it should go to sleep in deep sleep mode.

```c
/*
* Power source check:
* Look for EXT_PWR pin. If there's an external power adapter connected,
* Initialize RTC, enable Boost and all other peripherals. Run system.
* If no voltage in EXT_PWR, it means that battery has been connected first.
* In that case, do nothing and go to sleep.
*/
if(EXT_PWR) {
    sleep_mode = RTC_ENABLE;
    system_state = SYSTEM_INTRO;
    peripherals_enable();
    led_blink(3, 40);
    uart_send_string_p(PSTR("\n\rFirmware Version: "));
    uart_send_string_p(PSTR(FIRMWARE_DATE));
    uart_send_string_p(PSTR("\n\r"));
} else {
    sleep_mode = RTC_DISABLE;
    system_state = SYSTEM_SLEEP;
} 
```

If no external power is found, some initialization tests are skipped, like factory test and voltages test, and it jumps right into the `go_to_sleep()` function, inside of which execution flow follows the same pattern described above.

### Operation frequency

MCU operation frequency range is dependent on supply voltage. Datasheet gives:

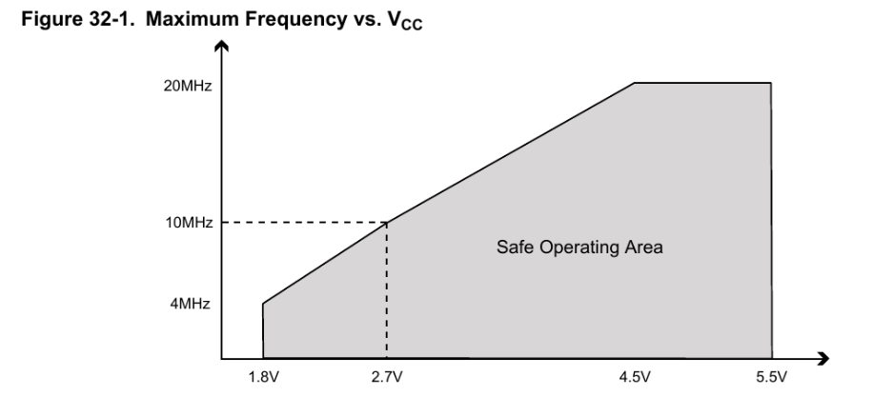
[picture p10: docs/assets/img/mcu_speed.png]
MCU speed grah MCU speed dependency


There's an on board __16MHz__ ceramic resonator. Since the MCU is expected to work with a coin cell battery voltage of about 2.7V minimum, the maximum allowed frequency is __10MHz__. Nevertheless, the MCU offers only one option to prescale the external clock source: enabling a configuration fuse that sets a prescale factor of 8. At the top of `main.c` there's a section for fuses configuration.

```c
#define FUSE_BITS_LOW       (FUSE_SUT_CKSEL0 & FUSE_CKDIV8)
```

The bit mask `FUSE_CKDIV8` sets the use of the prescaler by 8. Thus, the CPU frequency is set to be __2MHz__. This is also stated in `config.h`:

```c
// 16MHz ceramic resonator, prescaled by 8
#define F_CPU			2000000UL
// A non-usual baud rate, but it's needed due to the low operating frequency,
// so that it may work with no errors
#define BAUD 			125000UL
```

As a consequence, the [baud rate](https://en.wikipedia.org/wiki/Symbol_rate) for serial communications is forced to be a non-standard rate of `125.000` bauds. Lower values provoke slower communication rates and generate a slight flickering on the display every second. A valid standard baud rate is `19.200`, although the flickering effect is notorious.

I've been able to use the `125.000` baud rate using off-the-shelf usb to serial adapters and [PuTTY](https://www.putty.org/) as virtual COM port under windows. No problems whatsoever. On the other hand, I've not been able to use PuTTY under Linux with non-standard baud rates. I also tried [minicom](https://linux.die.net/man/1/minicom), but no success.

Lower CPU frequencies is also advantageous: it presents lower power consumption, although it takes more time to execute tasks and go to sleep.

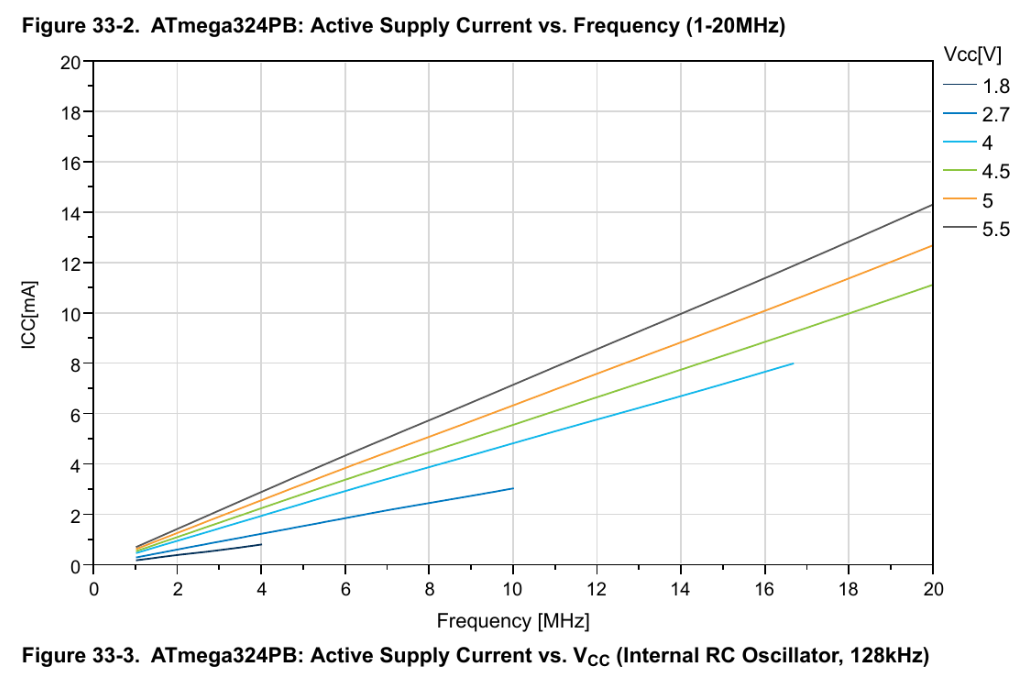
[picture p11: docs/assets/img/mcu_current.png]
MCU power consumption


Further testing might be needed in order to determine the exact power consumption of the MCU and a more accurate estimate of the coin cell battery life.

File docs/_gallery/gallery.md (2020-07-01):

---
title:  "Gallery"
permalink: /gallery/
---

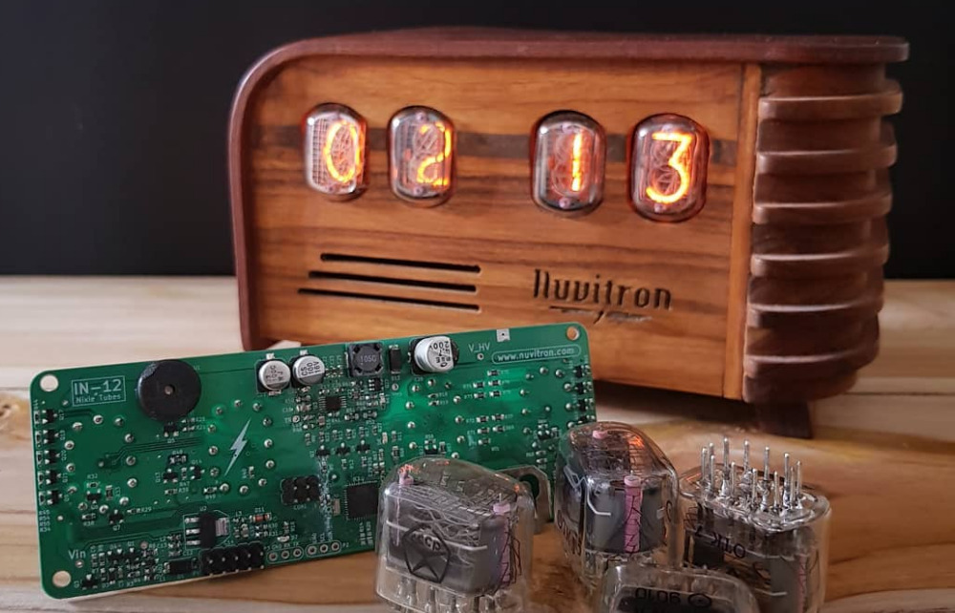
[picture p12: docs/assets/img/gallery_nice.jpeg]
Gallery 1


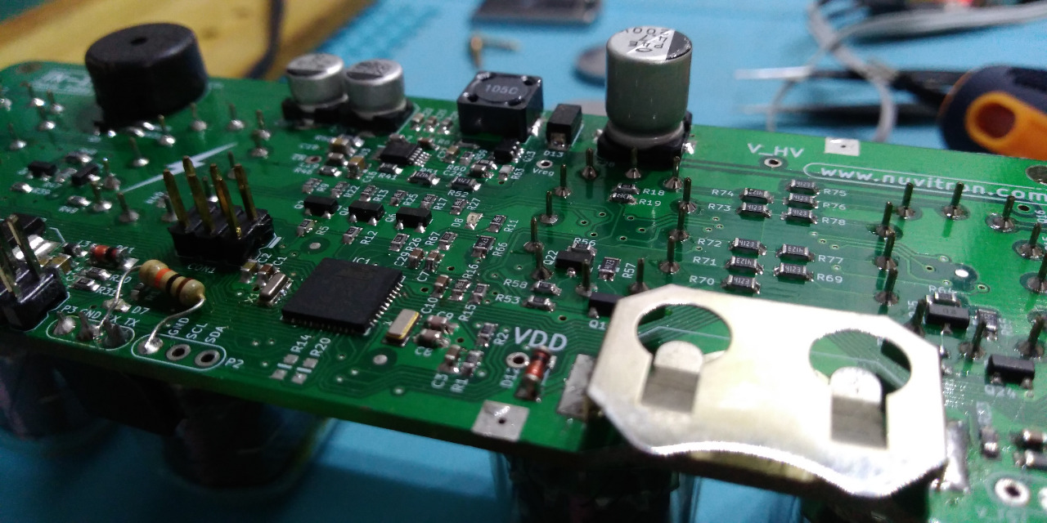
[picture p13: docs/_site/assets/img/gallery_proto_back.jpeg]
Gallery 2


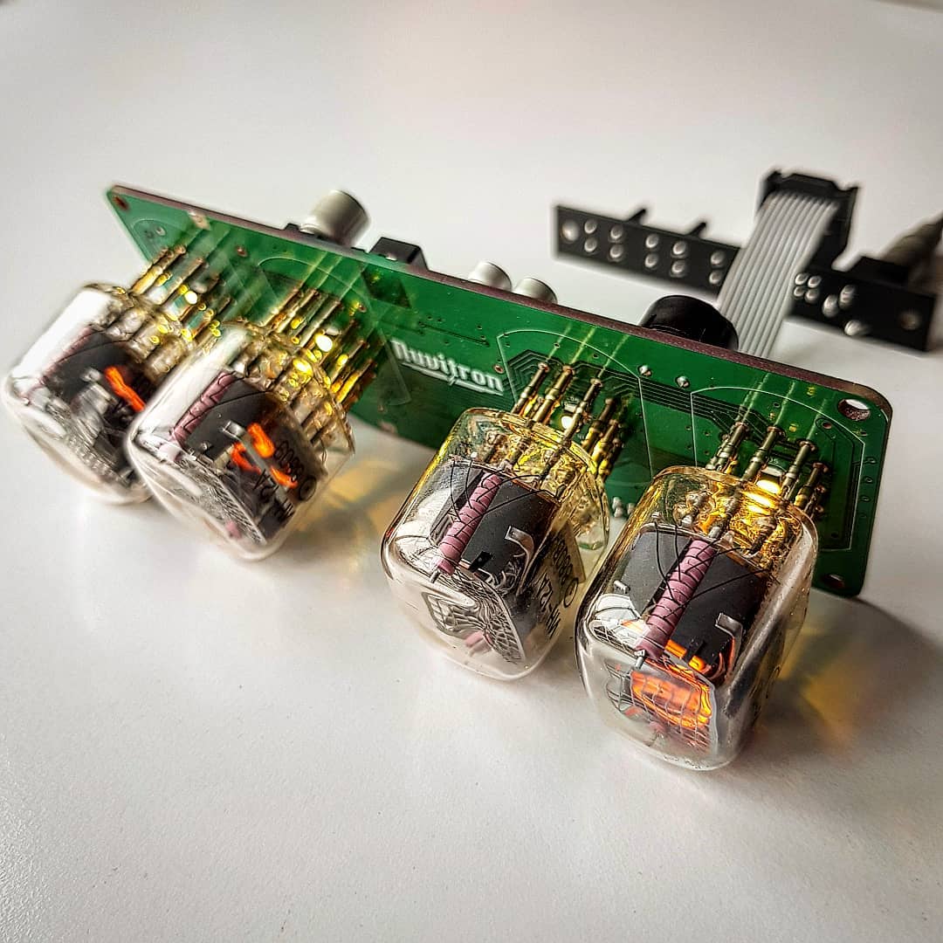
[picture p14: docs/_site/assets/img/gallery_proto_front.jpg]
Gallery 3


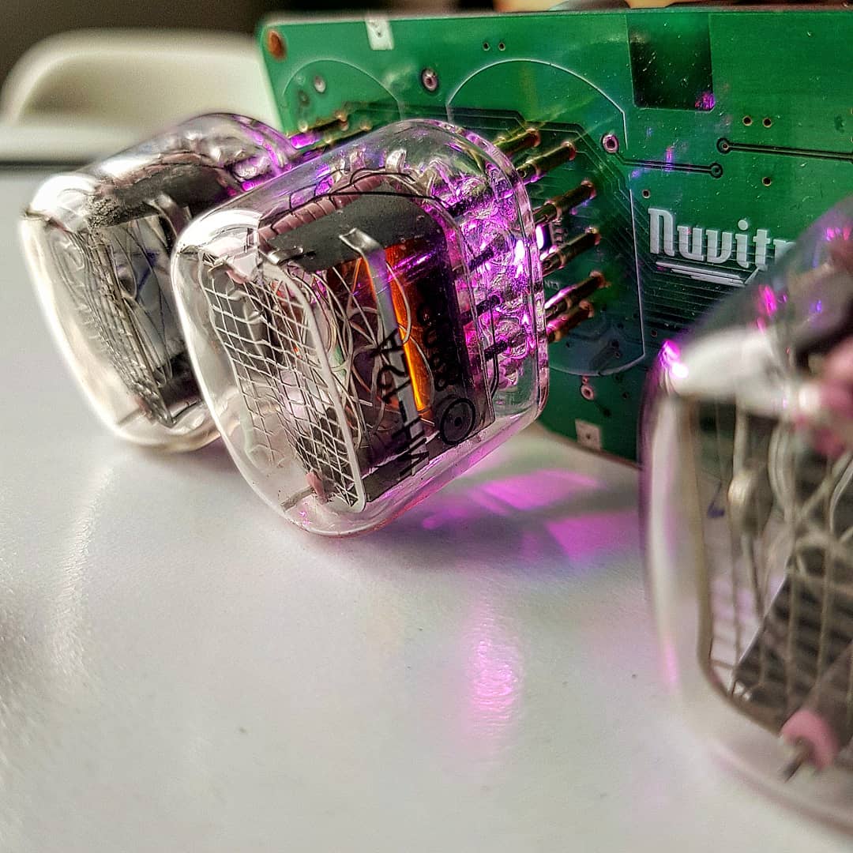
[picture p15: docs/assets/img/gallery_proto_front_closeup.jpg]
Gallery 4


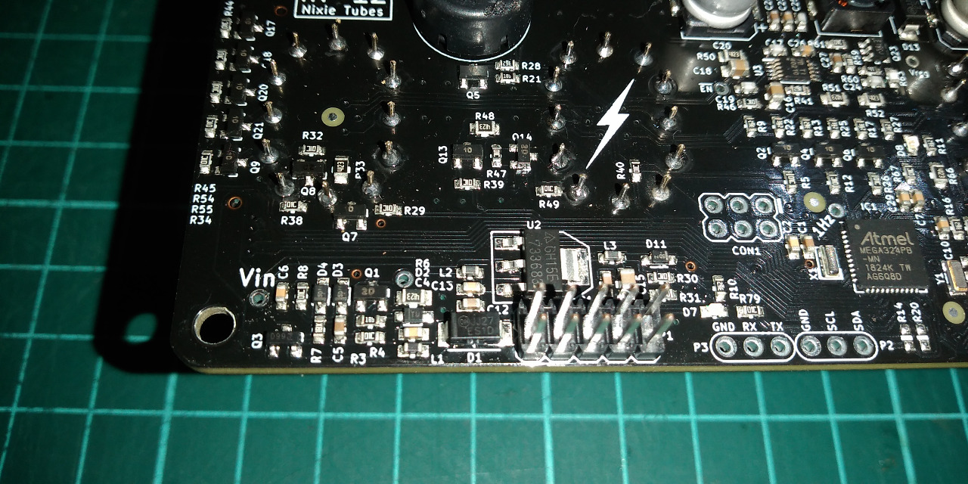
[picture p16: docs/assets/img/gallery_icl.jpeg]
Gallery 5


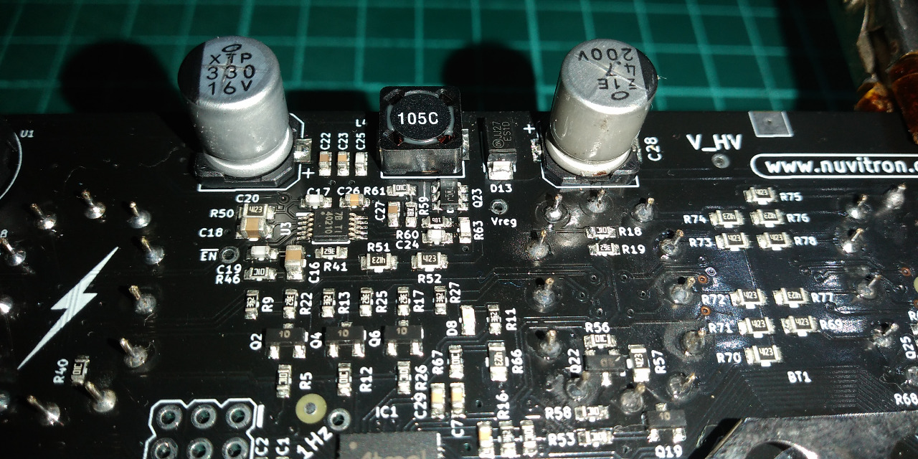
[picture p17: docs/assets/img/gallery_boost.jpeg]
Gallery 6


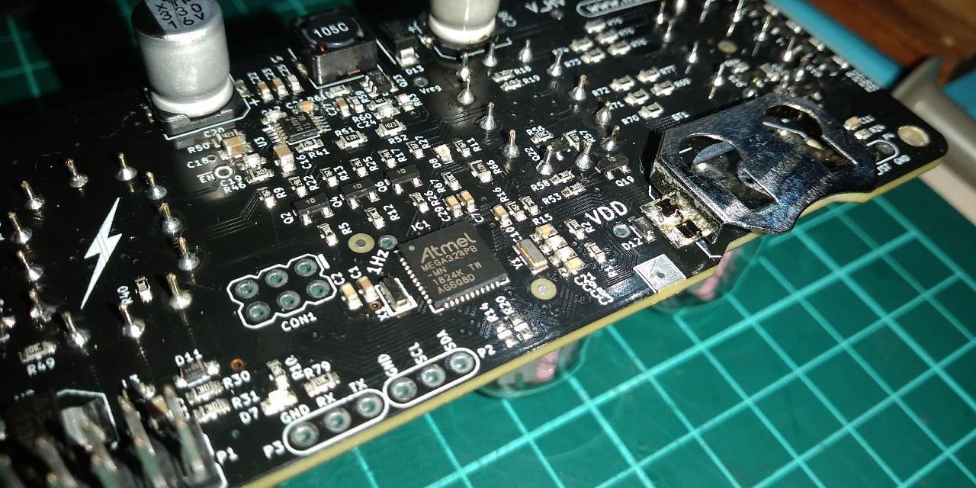
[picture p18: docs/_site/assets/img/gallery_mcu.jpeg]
Gallery 7


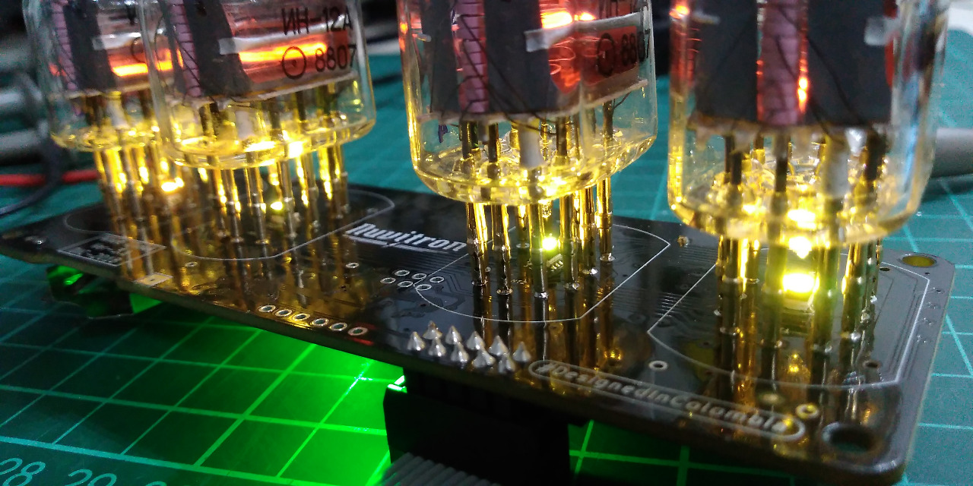
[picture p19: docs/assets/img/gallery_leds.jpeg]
Gallery 8


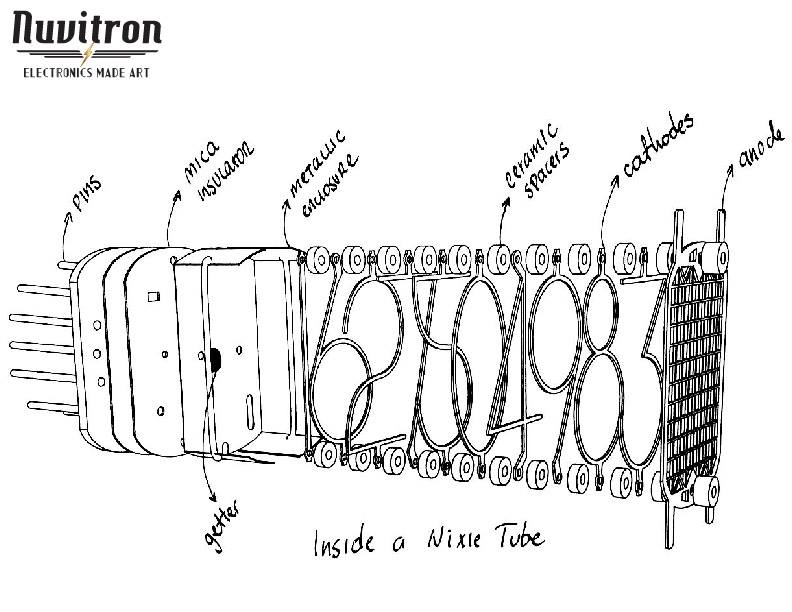
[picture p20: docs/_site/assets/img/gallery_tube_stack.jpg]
Gallery 9


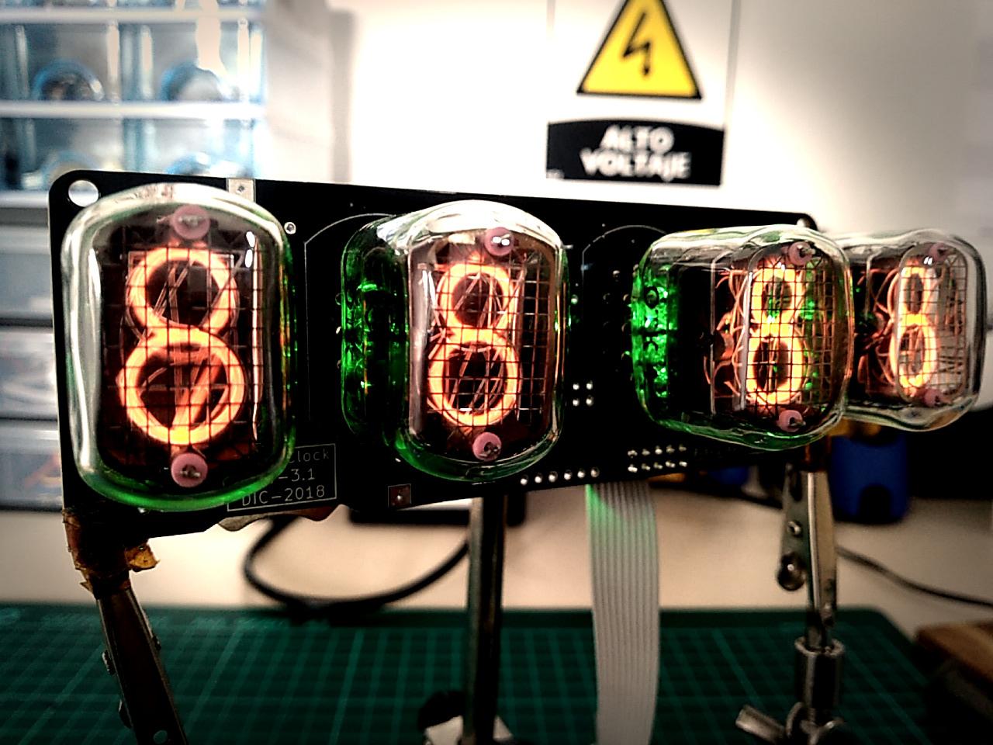
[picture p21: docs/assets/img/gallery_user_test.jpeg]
Gallery 10


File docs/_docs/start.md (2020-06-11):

---
title: Welcome
permalink: /docs/start/
---

## Getting Started

There're many good designs out there in the wilderness. To the point of this writting I've lost track of most of them, but they are not hard to find. 

I think this design includes some intresting tradeoffs worth looking, and some very neat hardware and software artifacts that give this project a plus.

My interest is __NOT__ to fully document the work done, but to __highlight__ some key points that aren't easy to figure out.

+ Head over to the left navigation menu and explore some of them
+ Or jump right into the [source](https://github.com/joselogreira/nixie_clock) to look under the hood.
+ Read through the [README.md](https://github.com/joselogreira/nixie_clock/blob/master/README.md) file for a quick description of the toolchain used for programming.

___ENJOY!___

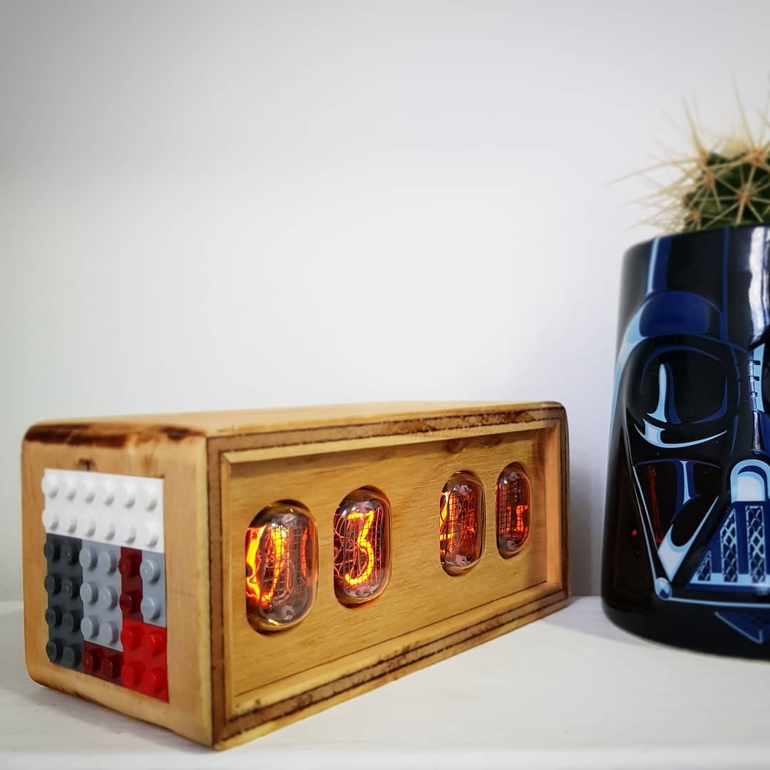
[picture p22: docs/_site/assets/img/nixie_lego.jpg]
lego


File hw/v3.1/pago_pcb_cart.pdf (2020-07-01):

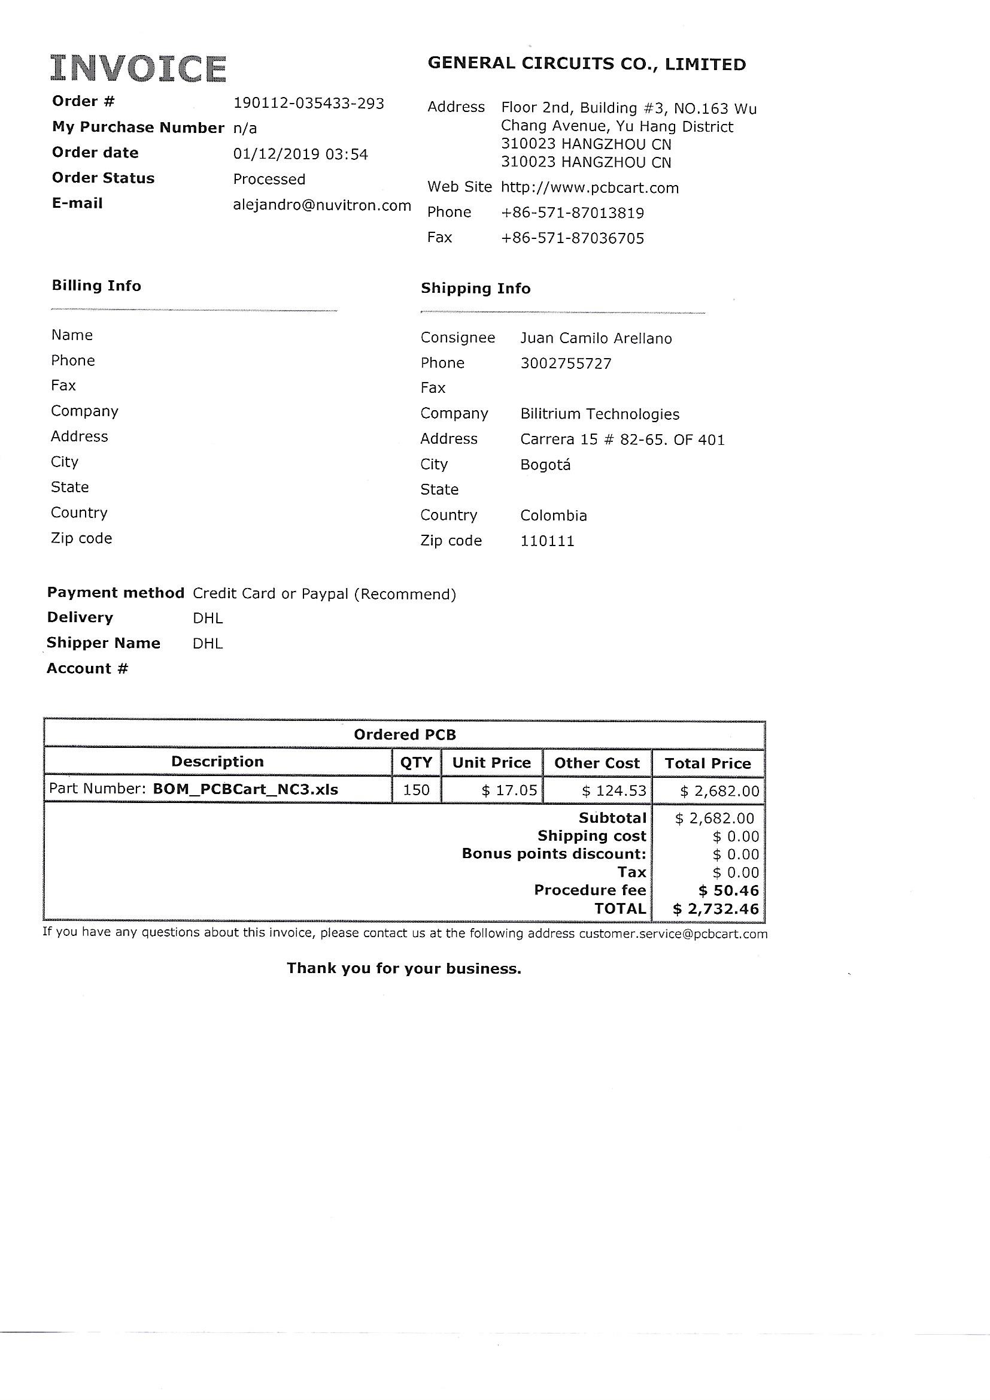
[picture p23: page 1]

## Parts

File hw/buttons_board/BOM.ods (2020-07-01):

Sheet: Hoja1
Part/Device Description | QTY | Reference Designator | MFR Part No | Notes | WEB
CONN PWR JACK 2.1X5.5MM VERT | 1 |  | PJ-006A |  | http://www.digikey.com/product-detail/en/cui-inc/PJ-006A/CP-006A-ND/269296
8 Positions Header, Unshrouded, Breakaway Connector 0.100" (2.54mm) Through Hole Tin | 1 |  | M20-9980446 |  | http://www.digikey.com/product-detail/en/harwin-inc/M20-9980446/952-2123-ND/3728087
Tactile Switch SPST-NO Top Actuated Through Hole | 3 |  | 3-1825910-1 |  | http://www.digikey.com/product-detail/en/te-connectivity-alcoswitch-switches/3-1825910-1/450-1643-ND/1632529

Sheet: Hoja2
fs | 1
Ct | 1
Rt
 | 1,50E-010 | 58823,5294117647

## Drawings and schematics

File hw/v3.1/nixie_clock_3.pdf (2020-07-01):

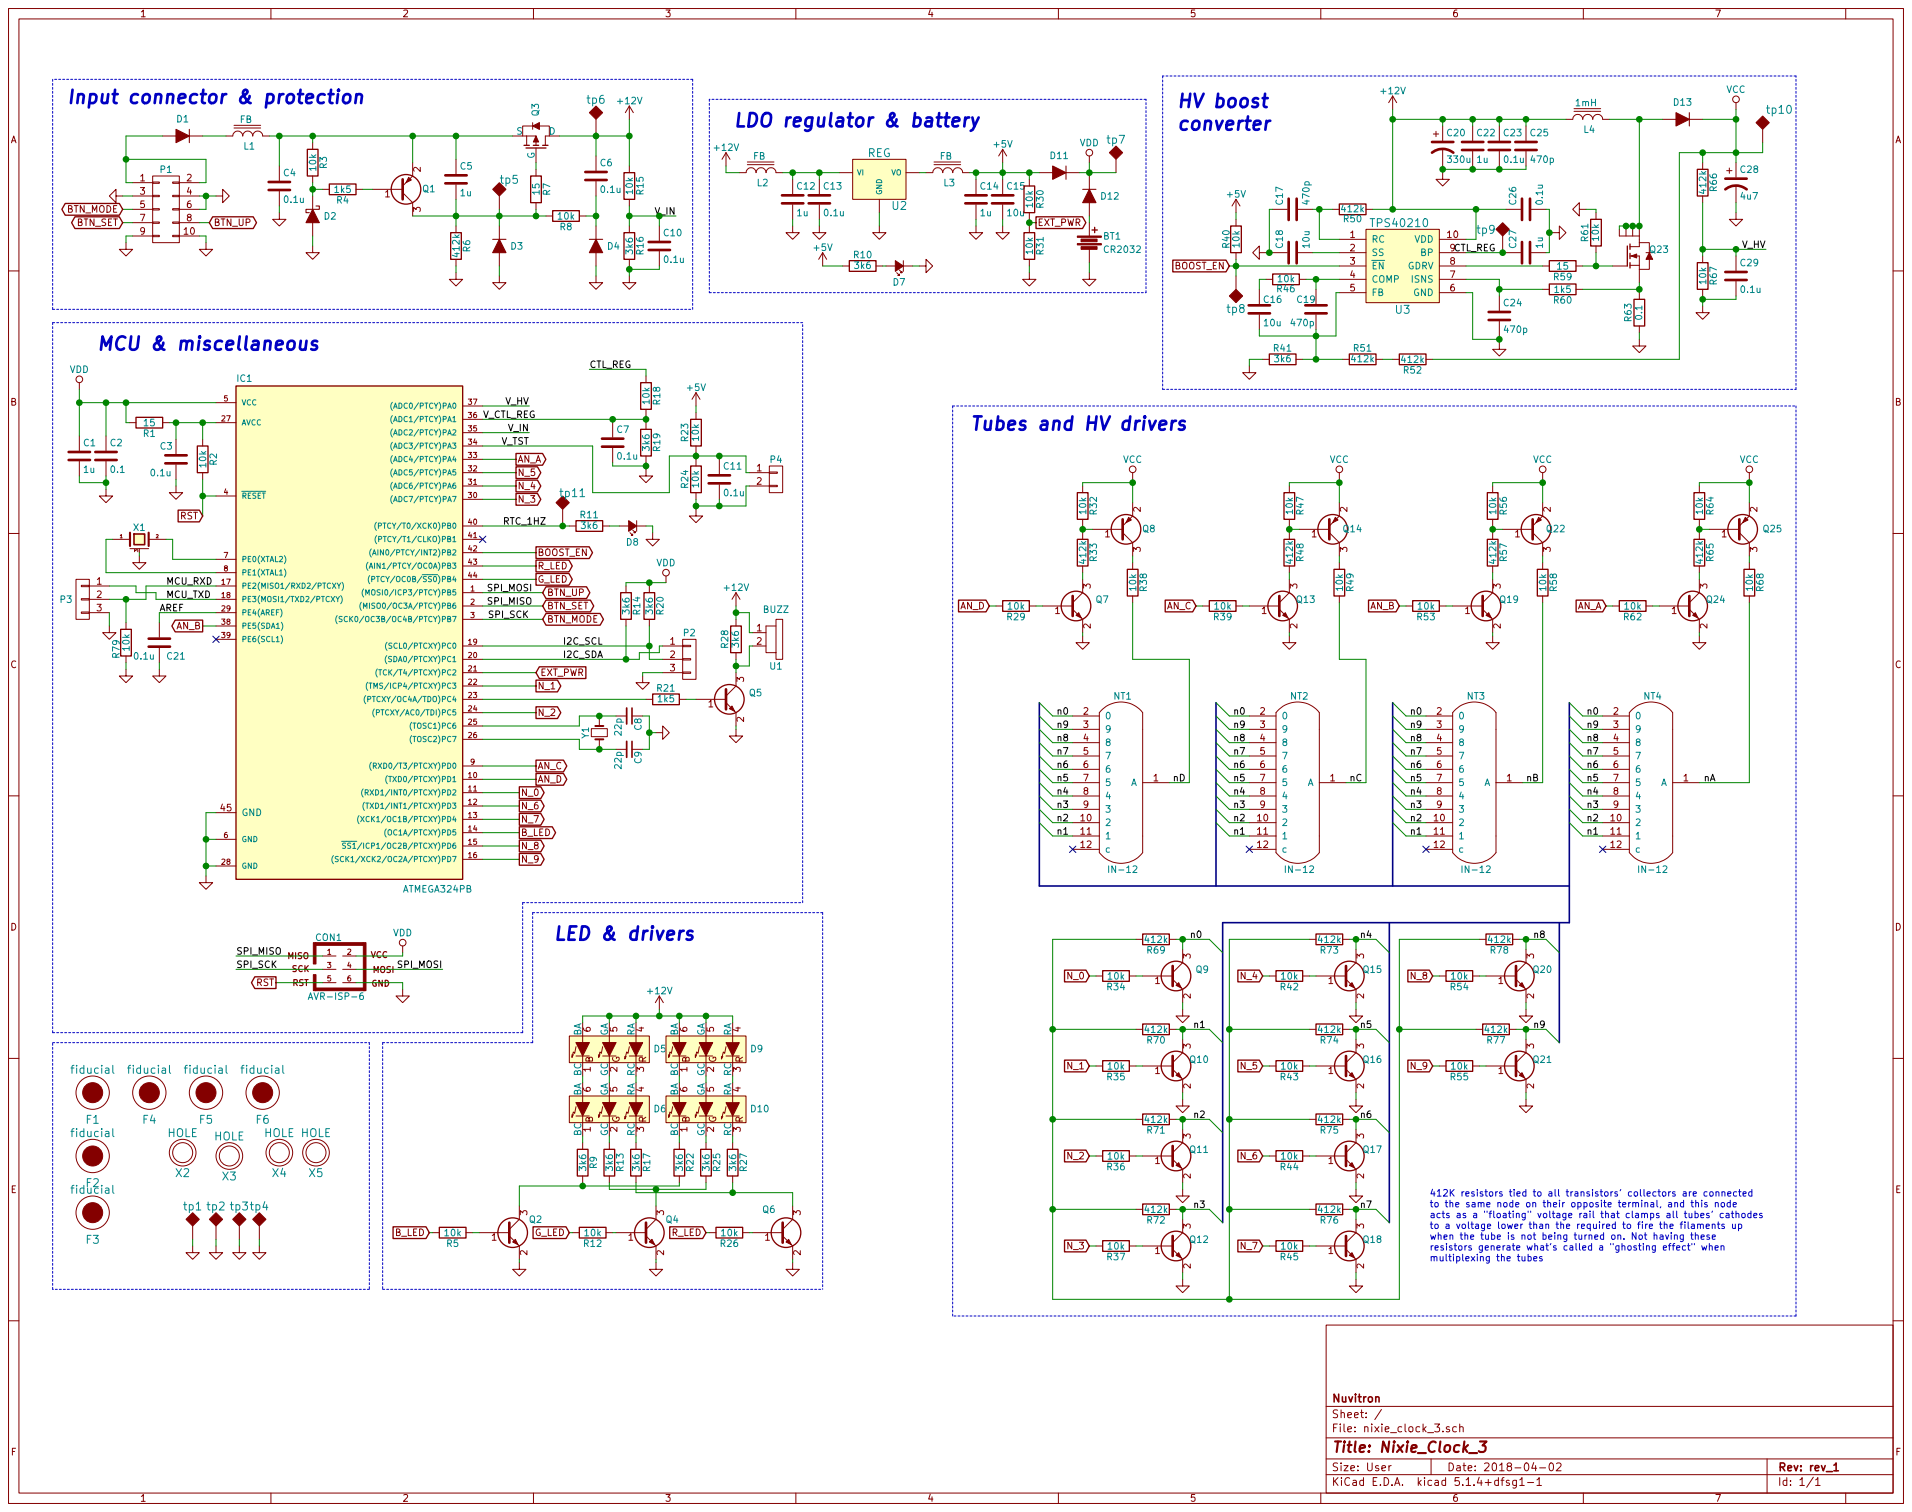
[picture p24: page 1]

Tubes and HV drivers

412K resistors tied to all transistors' collectors are connected
to the same node on their opposite terminal, and this node
acts as a "floating" voltage rail that clamps all tubes' cathodes
to a voltage lower than the required to fire the filaments up
when the tube is not being turned on. Not having these
resistors generate what's called a "ghosting effect" when
multiplexing the tubes

File: nixie_clock_3.sch Sheet: / Nuvitron

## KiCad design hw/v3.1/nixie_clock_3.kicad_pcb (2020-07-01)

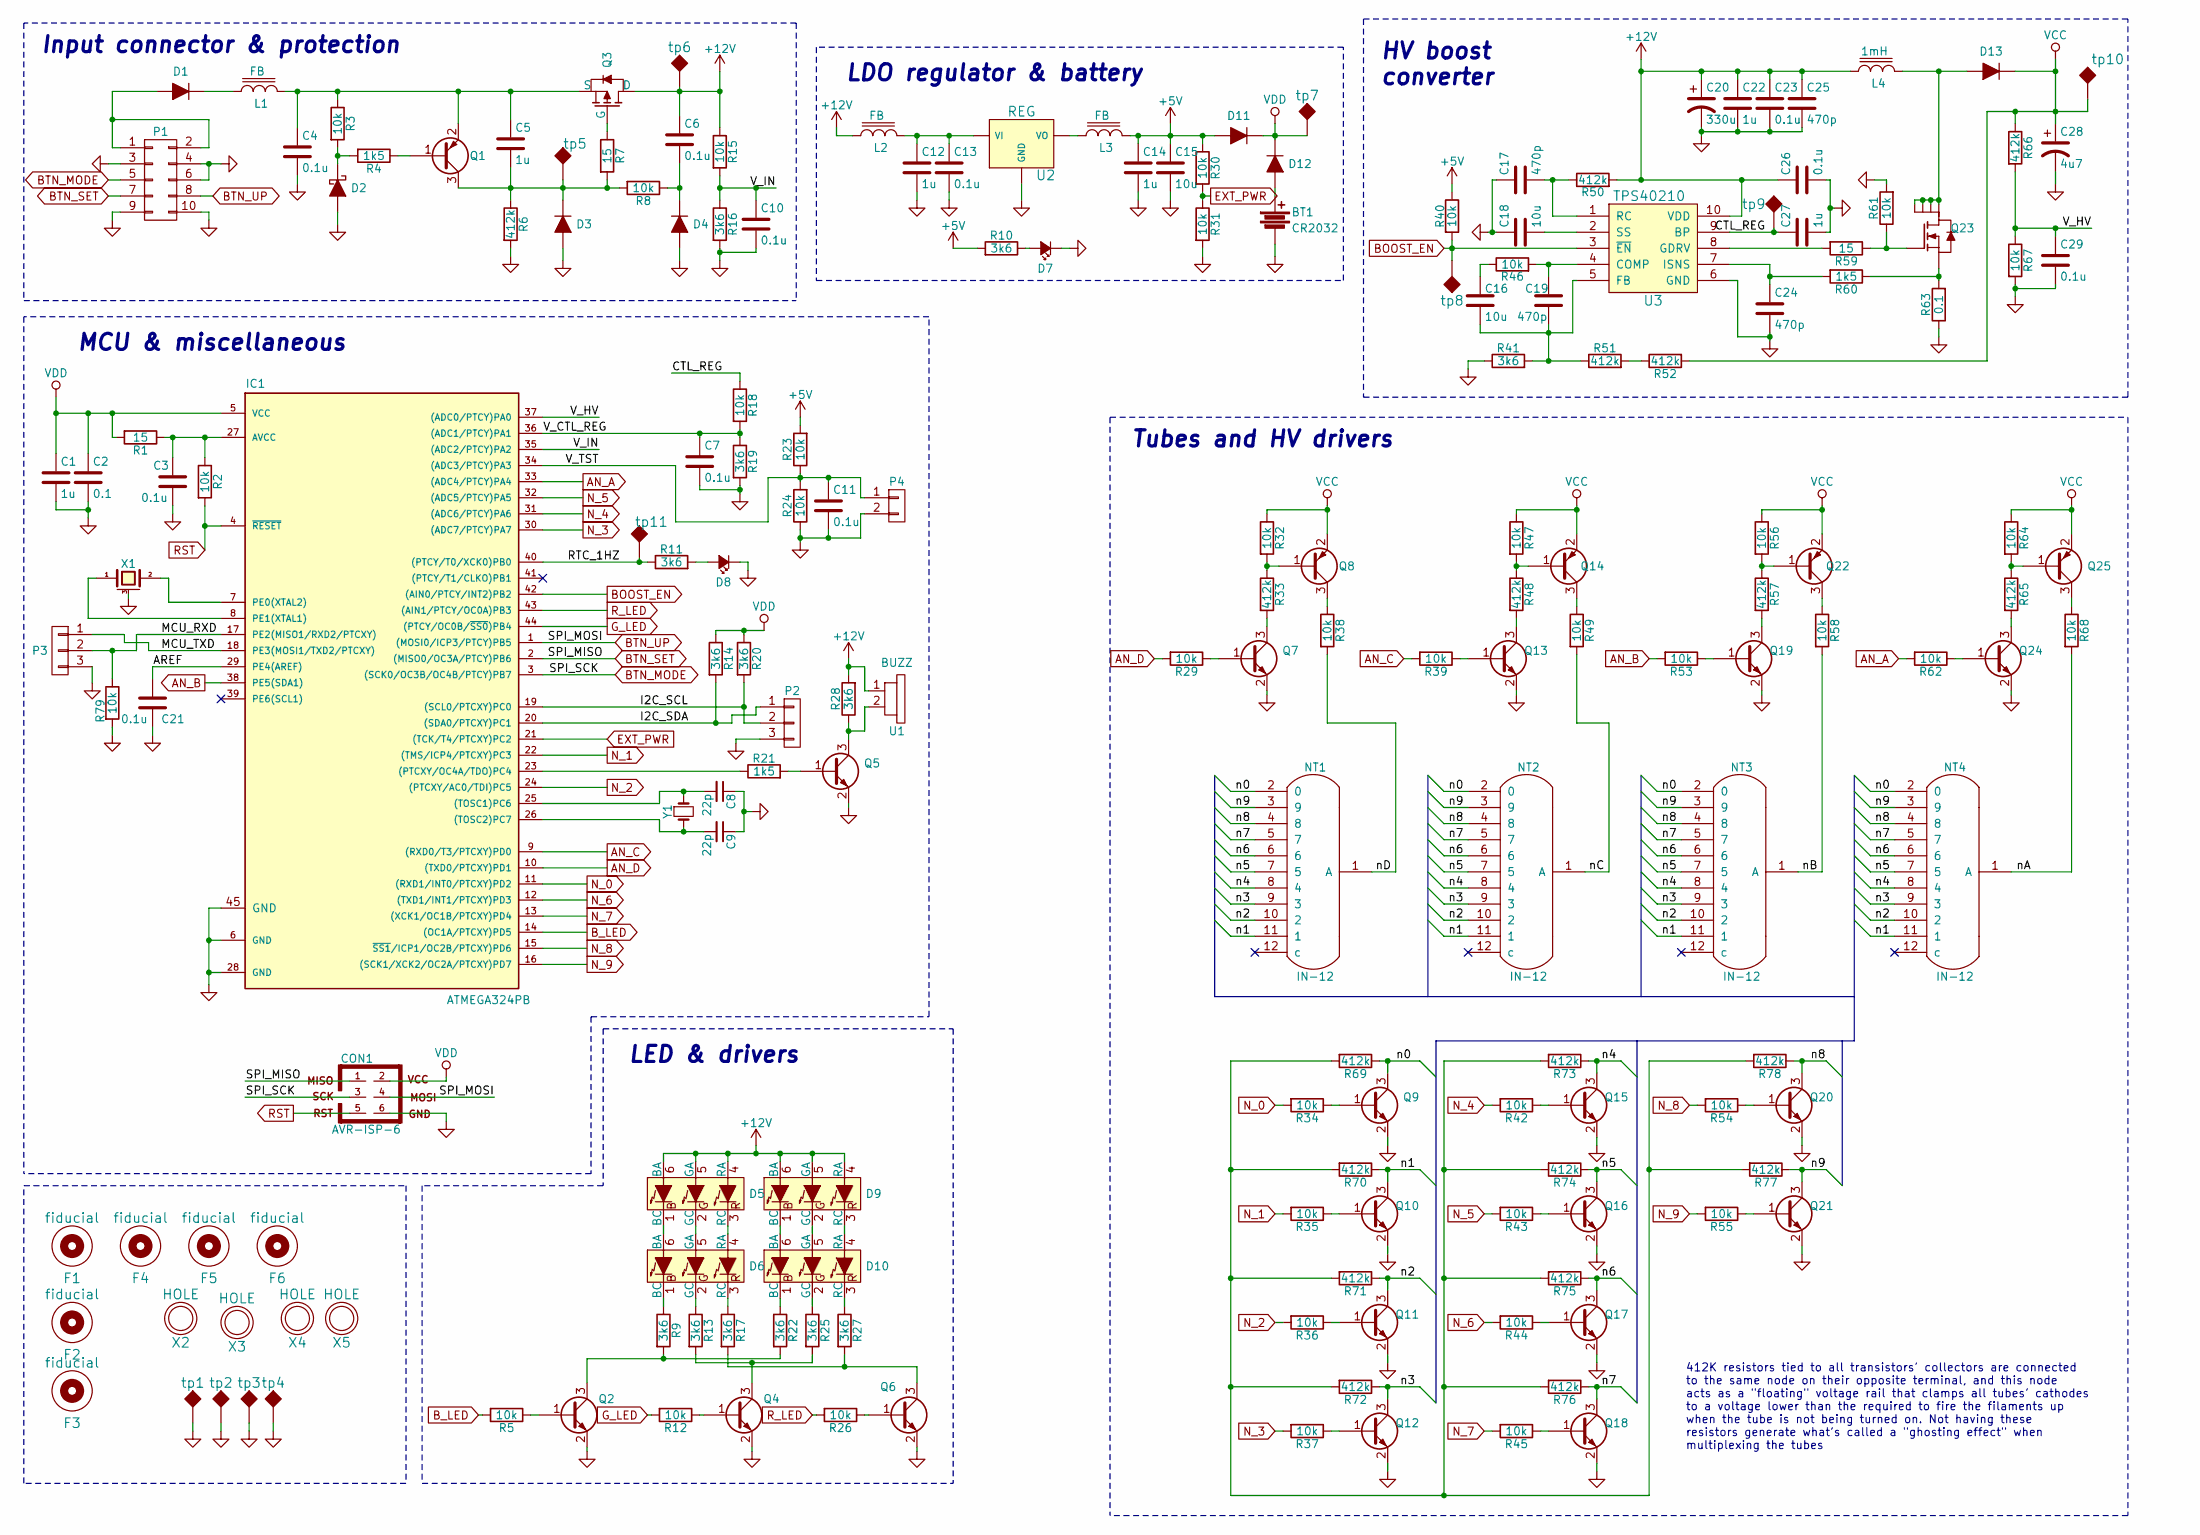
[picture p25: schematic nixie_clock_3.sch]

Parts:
BT1: CR2032
C1, C5, C12, C14, C22, C27: 1u; C_0603
C2: 0.1; C_0603
C3, C4, C6, C7, C10, C11, C13, C21, C23, C26, C29: 0.1u; C_0603
C8, C9: 22p; C_0603
C15, C16, C18: 10u; C_0805
C17, C19, C24, C25: 470p; C_0603
C20: 330u; CP_Elec_8x10
C28: 4u7; CP_Elec_8x10
CON1: AVR-ISP-6; ISP_THT_UNPOPULATED
D1, D13: D_ALT; DO-214AC
D2: D_Schottky_ALT; SOD-323
D3, D4, D11, D12: D_ALT; SOD-323
D5, D6, D9, D10: LED_RGB_IND; LED_RGB_PLCC-6-SMALL
D7, D8: Led_Small; D_0603
F1, F2, F3, F4, F5, F6: fiducial; Fiducial_1mm_Dia_2.54mm_Outer_CopperTop
IC1: ATMEGA324PB; QFN-44-1EP_7x7mm_Pitch0.5mm
L1, L2, L3: FB; C_0603
L4: 1mH; IND_1MH_7.3x7.3mm
NT1, NT2, NT3, NT4: IN-12
P1: CONN_02X05; CON_2x5
P2, P3: CONN_01X03; CON_1x3
P4: CONN_01X02; CON_1x2
Q1, Q8, Q14, Q22, Q25: Q_PNP_BEC; SOT-23
Q2, Q4, Q5, Q6, Q7, Q9, Q10, Q11, Q12, Q13, Q15, Q16, Q17, Q18, Q19, Q20, Q21, Q24: Q_NPN_BEC; SOT-23
Q3: Q_PMOS_GSD_; SOT-23
Q23: Q_NMOS_GSD_6; SOT-23-6
R1, R7, R59: 15; C_0603
R2, R3, R5, R8, R12, R15, R18, R23, R24, R26, R29, R30, R31, R32, R34, R35, R36, R37, R38, R39, R40, R42, R43, R44, R45, R46, R47, R49, R53, R54, R55, R56, R58, R61, R62, R64, R67, R68, R79: 10k; C_0603
R4, R21, R60: 1k5; C_0603
R6, R33, R48, R50, R51, R52, R57, R65, R66, R69, R70, R71, R72, R73, R74, R75, R76, R77, R78: 412k; C_0805
R9, R10, R11, R13, R14, R16, R17, R19, R20, R22, R25, R27, R28, R41: 3k6; C_0603
R63: 0.1; C_0603
U1: BUZZ; BUZZ-D12,6_P5
U2: REG; SOT-223
U3: TPS40210; 10-MSOP
X1: CRYSTAL_SMD; CERAMIC_RESONATOR
X2, X3, X4, X5: HOLE; MOUNTING_NPTH_3.2MM
Y1: Crystal_Small; Crystal_3.2x1.5mm
tp1, tp2, tp3, tp4: tp; TestPoint_Pad_3.0x3.0mm
tp5, tp6, tp7, tp8, tp9, tp10, tp11: tp

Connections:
+5V: C14.1, C15.1, D11.2 (A), L3.1, R10.2, R23.2, R30.1, R40.1
+12V: C6.1, C20.1, C22.1, C23.1, C25.1, C26.1, D5.4 (RA), D5.5 (GA), D5.6 (BA), D9.4 (RA), D9.5 (GA), D9.6 (BA), L2.2, L4.2, Q3.3 (D), R15.1, R28.2, R50.2, U1.1, U3.10 (VDD), tp6.1
/AREF: C21.1, IC1.29 (PE4(AREF))
/CTL_REG: C27.1, R18.1, U3.9 (BP), tp9.1
/I2C_SCL: IC1.19 ((SCL0/PTCXY)PC0), P2.2, R20.2
/I2C_SDA: IC1.20 ((SDA0/PTCXY)PC1), P2.1, R14.2
/MCU_RXD: IC1.17 (PE2(MISO1/RXD2/PTCXY)), P3.2, R79.1
/MCU_TXD: IC1.18 (PE3(MOSI1/TXD2/PTCXY)), P3.1
/RTC_1HZ: IC1.40 ((PTCY/T0/XCK0)PB0), R11.1, tp11.1
/V_CTL_REG: C7.1, IC1.36 ((ADC1/PTCY)PA1), R18.2, R19.1
/V_HV: C29.1, IC1.37 ((ADC0/PTCY)PA0), R66.2, R67.1
/V_IN: C10.1, IC1.35 ((ADC2/PTCY)PA2), R15.2, R16.1
/V_TST: C11.1, IC1.34 ((ADC3/PTCY)PA3), P4.1, R23.1, R24.2
/n0: NT1.2 (0), NT2.2 (0), NT3.2 (0), NT4.2 (0), Q9.3 (C), R69.1
/n1: NT1.11 (1), NT2.11 (1), NT3.11 (1), NT4.11 (1), Q10.3 (C), R70.1
/n2: NT1.10 (2), NT2.10 (2), NT3.10 (2), NT4.10 (2), Q11.3 (C), R71.1
/n3: NT1.9 (3), NT2.9 (3), NT3.9 (3), NT4.9 (3), Q12.3 (C), R72.1
/n4: NT1.8 (4), NT2.8 (4), NT3.8 (4), NT4.8 (4), Q15.3 (C), R73.1
/n5: NT1.7 (5), NT2.7 (5), NT3.7 (5), NT4.7 (5), Q16.3 (C), R74.1
/n6: NT1.6, NT2.6, NT3.6, NT4.6, Q17.3 (C), R75.1
/n7: NT1.5 (7), NT2.5 (7), NT3.5 (7), NT4.5 (7), Q18.3 (C), R76.1
/n8: NT1.4 (8), NT2.4 (8), NT3.4 (8), NT4.4 (8), Q20.3 (C), R78.1
/n9: NT1.3 (9), NT2.3 (9), NT3.3 (9), NT4.3 (9), Q21.3 (C), R77.1
/nA: NT4.1 (A), R68.2
/nB: NT3.1 (A), R58.2
/nC: NT2.1 (A), R49.2
/nD: NT1.1 (A), R38.2
AN_A: IC1.33 ((ADC4/PTCY)PA4), R62.2
AN_B: IC1.38 (PE5(SDA1)), R53.2
AN_C: IC1.9 ((RXD0/T3/PTCXY)PD0), R39.2
AN_D: IC1.10 ((TXD0/PTCXY)PD1), R29.2
BOOST_EN: IC1.42 ((AIN0/PTCY/INT2)PB2), R40.2, U3.3 (~EN), tp8.1
BTN_MODE: CON1.3, IC1.3 ((SCK0/OC3B/OC4B/PTCY)PB7), P1.5
BTN_SET: CON1.1, IC1.2 ((MISO0/OC3A/PTCY)PB6), P1.7
BTN_UP: CON1.4, IC1.1 ((MOSI0/ICP3/PTCY)PB5), P1.8
B_LED: IC1.14 ((OC1A/PTCXY)PD5), R5.2
EXT_PWR: IC1.21 ((TCK/T4/PTCXY)PC2), R30.2, R31.1
GND: BT1.2, C1.2, C2.2, C3.2, C4.2, C7.2, C8.1, C9.1, C10.2, C11.2, C12.2, C13.2, C14.2, C15.2, C17.1, C18.1, C20.2, C21.2, C22.2, C23.2, C24.2, C25.2, C26.2, C27.2, C28.2, C29.2, CON1.6, D2.2 (A), D3.2 (A), D4.2 (A), D7.1 (K), D8.1 (K), IC1.6 (GND), IC1.28 (GND), IC1.45 (GND), P1.3, P1.4, P1.6, P1.9, P1.10, P2.3, P3.3, P4.2, Q2.2 (E), Q4.2 (E), Q5.2 (E), Q6.2 (E), Q7.2 (E), Q9.2 (E), Q10.2 (E), Q11.2 (E), Q12.2 (E), Q13.2 (E), Q15.2 (E), Q16.2 (E), Q17.2 (E), Q18.2 (E), Q19.2 (E), Q20.2 (E), Q21.2 (E), Q24.2 (E), R6.2, R16.2, R19.2, R24.1, R31.2, R41.1, R61.2, R63.1, R67.2, R79.2, U2.1 (GND), U3.6 (GND), X1.3 (case), tp1.1, tp2.1, tp3.1, tp4.1
G_LED: IC1.44 ((PTCY/OC0B/~SS0~)PB4), R12.2
N_0: IC1.11 ((RXD1/INT0/PTCXY)PD2), R34.2
N_1: IC1.22 ((TMS/ICP4/PTCXY)PC3), R35.2
N_2: IC1.24 ((PTCXY/AC0/TDI)PC5), R36.2
N_3: IC1.30 ((ADC7/PTCY)PA7), R37.2
N_4: IC1.31 ((ADC6/PTCY)PA6), R42.2
N_5: IC1.32 ((ADC5/PTCY)PA5), R43.2
N_6: IC1.12 ((TXD1/INT1/PTCXY)PD3), R44.2
N_7: IC1.13 ((XCK1/OC1B/PTCXY)PD4), R45.2
N_8: IC1.15 (~SS1~/ICP1/OC2B/PTCXY)PD6), R54.2
N_9: IC1.16 ((SCK1/XCK2/OC2A/PTCXY)PD7), R55.2
unnamed: BT1.1, D12.2 (A)
unnamed: C3.1, IC1.27 (AVCC), R1.1, R2.1
unnamed: C4.1, C5.1, L1.1, Q1.2 (E), Q3.2 (S), R3.1
unnamed: C5.2, D3.1 (K), Q1.3 (C), R6.1, R7.2, R8.2, tp5.1
unnamed: C6.2, D4.1 (K), R8.1
unnamed: C8.2, IC1.25 ((TOSC1)PC6), Y1.1
unnamed: C9.2, IC1.26 ((TOSC2)PC7), Y1.2
unnamed: C12.1, C13.1, L2.1, U2.3 (VI)
unnamed: C16.1, R46.1
unnamed: C16.2, C19.2, R41.2, R51.1, U3.5 (FB)
unnamed: C17.2, R50.1, U3.1 (RC)
unnamed: C18.2, U3.2 (SS)
unnamed: C19.1, R46.2, U3.4 (COMP)
unnamed: C24.1, R60.2, U3.7 (ISNS)
unnamed: D1.1 (K), L1.2
unnamed: D1.2 (A), P1.1, P1.2
unnamed: D2.1 (K), R3.2, R4.2
unnamed: D5.1 (BC), D6.6 (BA)
unnamed: D5.2 (GC), D6.5 (GA)
unnamed: D5.3 (RC), D6.4 (RA)
unnamed: D6.1 (BC), R9.1
unnamed: D6.2 (GC), R13.1
unnamed: D6.3 (RC), R17.1
unnamed: D7.2 (A), R10.1
unnamed: D8.2 (A), R11.2
unnamed: D10.1 (BC), R22.1
unnamed: D10.2 (GC), R25.1
unnamed: D10.3 (RC), R27.1
unnamed: D9.3 (RC), D10.4 (RA)
unnamed: D9.2 (GC), D10.5 (GA)
unnamed: D9.1 (BC), D10.6 (BA)
unnamed: D13.2 (A), L4.1, Q23.1, Q23.2 (D), Q23.5, Q23.6
unnamed: IC1.7 (PE0(XTAL2)), X1.2
unnamed: IC1.8 (PE1(XTAL1)), X1.1
unnamed: IC1.23 ((PTCXY/OC4A/TDO)PC4), R21.1
unnamed: L3.2, U2.2 (VO)
unnamed: Q1.1 (B), R4.1
unnamed: Q2.1 (B), R5.1
unnamed: Q2.3 (C), R9.2, R22.2
unnamed: Q3.1 (G), R7.1
unnamed: Q4.1 (B), R12.1
unnamed: Q4.3 (C), R13.2, R25.2
unnamed: Q5.1 (B), R21.2
unnamed: Q5.3 (C), R28.1, U1.2
unnamed: Q6.1 (B), R26.1
unnamed: Q6.3 (C), R17.2, R27.2
unnamed: Q7.1 (B), R29.1
unnamed: Q7.3 (C), R33.2
unnamed: Q8.1 (B), R32.2, R33.1
unnamed: Q8.3 (C), R38.1
unnamed: Q9.1 (B), R34.1
unnamed: Q10.1 (B), R35.1
unnamed: Q11.1 (B), R36.1
unnamed: Q12.1 (B), R37.1
unnamed: Q13.1 (B), R39.1
unnamed: Q13.3 (C), R48.2
unnamed: Q14.1 (B), R47.2, R48.1
unnamed: Q14.3 (C), R49.1
unnamed: Q15.1 (B), R42.1
unnamed: Q16.1 (B), R43.1
unnamed: Q17.1 (B), R44.1
unnamed: Q18.1 (B), R45.1
unnamed: Q19.1 (B), R53.1
unnamed: Q19.3 (C), R57.2
unnamed: Q20.1 (B), R54.1
unnamed: Q21.1 (B), R55.1
unnamed: Q22.1 (B), R56.2, R57.1
unnamed: Q22.3 (C), R58.1
unnamed: Q23.3 (G), R59.1, R61.1
unnamed: Q23.4 (S), R60.1, R63.2
unnamed: Q24.1 (B), R62.1
unnamed: Q24.3 (C), R65.2
unnamed: Q25.1 (B), R64.2, R65.1
unnamed: Q25.3 (C), R68.1
unnamed: R51.2, R52.1
unnamed: R59.2, U3.8 (GDRV)
unnamed: R69.2, R70.2, R71.2, R72.2, R73.2, R74.2, R75.2, R76.2, R77.2, R78.2
RST: CON1.5, IC1.4 (~RESET), R2.2
R_LED: IC1.43 ((AIN1/PTCY/OC0A)PB3), R26.2
VCC: C28.1, D13.1 (K), Q8.2 (E), Q14.2 (E), Q22.2 (E), Q25.2 (E), R32.1, R47.1, R52.2, R56.1, R64.1, R66.1, tp10.1
VDD: C1.1, C2.1, CON1.2, D11.1 (K), D12.1 (K), IC1.5 (VCC), R1.2, R14.1, R20.1, tp7.1

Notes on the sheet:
Input connector & protection
MCU & miscellaneous
HV boost converter
LDO regulator & battery
Tubes and HV drivers
LED & drivers
412K resistors tied to all transistors' collectors are connected to the same node on their opposite terminal, and this node acts as a "floating" voltage rail that clamps all tubes' cathodes to a voltage lower than the required to fire the filaments up when the tube is not being turned on. Not havin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

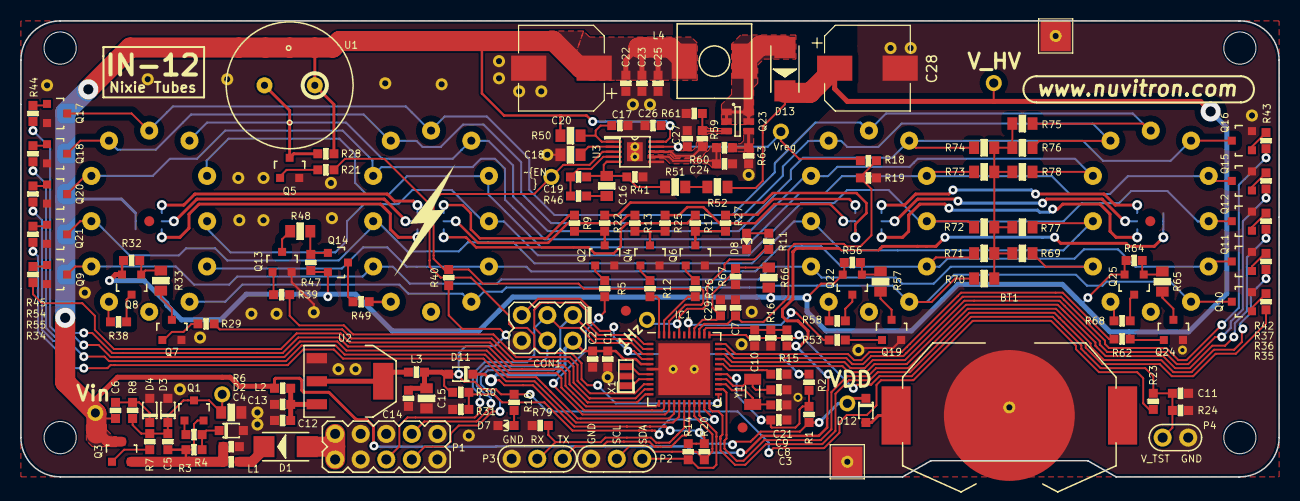
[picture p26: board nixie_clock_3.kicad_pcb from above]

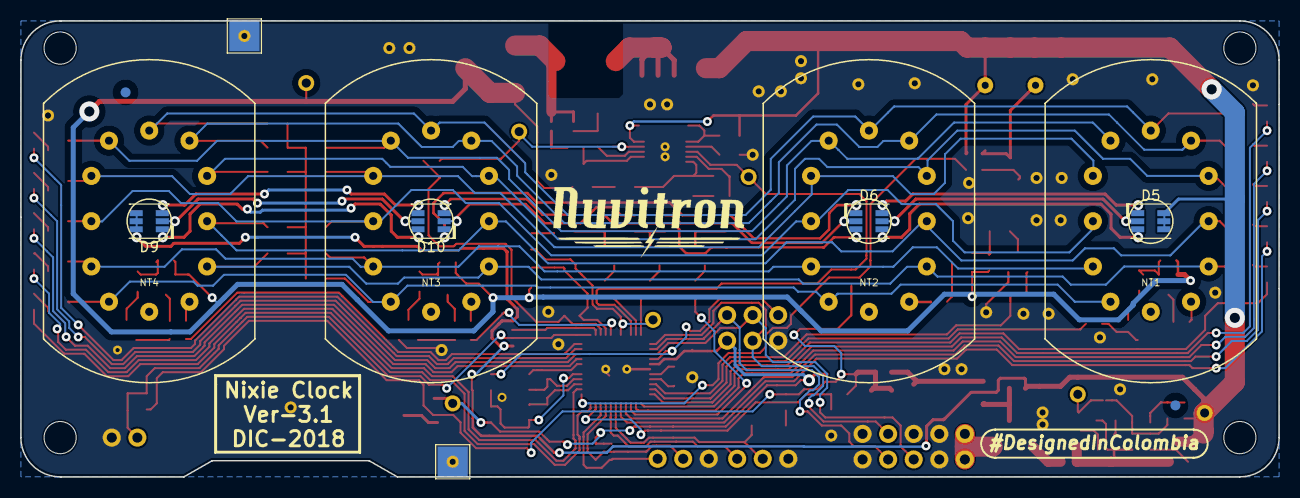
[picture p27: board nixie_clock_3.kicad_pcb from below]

Board: 2 copper layers, 125.0 x 45.3 mm, 187 parts (12 on the bottom side), 130 nets.

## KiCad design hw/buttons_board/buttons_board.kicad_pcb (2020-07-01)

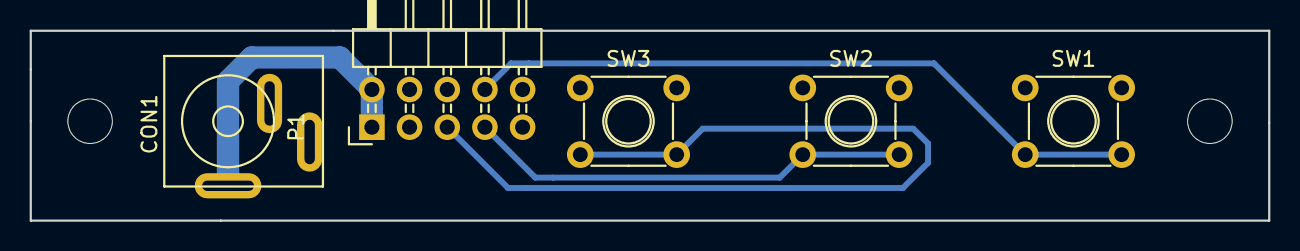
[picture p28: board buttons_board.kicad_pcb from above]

Board: 2 copper layers, 83.5 x 12.8 mm, 7 parts (0 on the bottom side), 5 nets.

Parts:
CON1: BARREL_JACK; CON_PWR_JACK_5.5x2mm
P1: CONN_02X05; Pin_Header_Angled_2x05
SW1: UP; SW_SPST_THT_6mm
SW2: SET; SW_SPST_THT_6mm
SW3: MODE; SW_SPST_THT_6mm
X1, X2: HOLE; MountingHole_3-5mm

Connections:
GND: CON1.2, CON1.3, P1.3, P1.4, P1.6, SW1.3, SW1.4, SW2.3, SW2.4, SW3.3, SW3.4
unnamed: CON1.1, P1.1, P1.2
unnamed: P1.5, SW3.1, SW3.2
unnamed: P1.7, SW2.1, SW2.2
unnamed: P1.8, SW1.1, SW1.2

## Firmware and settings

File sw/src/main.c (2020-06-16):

/**
 * @file main.c
 * @brief MAIN program resides here
 *
 * Main program structure:
 * - Basically, there's one infinite loop: the main application loop
 * - Usr/operator decides which one to enter at boot time, either using 
 *   buttons or by other mechanism
 * - Application loop: implemented as a big switch statement, similar to a
 *   Finite State Machine. States are linked to the information displayed and 
 *   clock actions
 * - Interrupts are only allowed in one case:
 *      - Wihin each system state function, at the end of every loop execution.
 *
 * @author Jose Logreira
 * @date 24.04.2018
 */

/******************************************************************************
******************* I N C L U D E   D E P E N D E N C I E S *******************
******************************************************************************/

#include "adc.h"
#include "config.h"
#include "debug.h"
#include "init.h"
#include "menu_alarm.h"
#include "menu_time.h"
#include "menu_user.h"
#include "sleep.h"
#include "timers.h"
#include "uart.h"
#include "util.h"

#include <stdint.h>         /* Standard variable types */
#include <avr/io.h>         /* Device specific ports/peripherals */ 
#include <avr/interrupt.h>  /* Global interrupts */
#include <util/delay.h>     /* Delay utility */
#include <avr/pgmspace.h>   /* Program Memory reading */

/******************************************************************************
********************* F U S E S   D E F I N I T I O N S ***********************
******************************************************************************/
/*
* These fuse settings will be placed in a special section in the ELF output 
* file, after linking. Programming tools can take advantage of the fuse info
* embedded in the ELF file, by extracting this information and determining if 
* the fuses need to be programmed before programming the Flash and EEPROM 
* memories. This also allows a single ELF file to contain all the information 
* needed to program an AVR.
*/

#define FUSE_BITS_LOW       (FUSE_SUT_CKSEL0 & FUSE_CKDIV8)                             // 0x7E
#define FUSE_BITS_HIGH      (FUSE_SPIEN & FUSE_EESAVE & FUSE_BOOTSZ1 & FUSE_BOOTSZ0)    // 0xD1
#define FUSE_BITS_EXTENDED  (FUSE_CFD & FUSE_BODLEVEL0)                                 // 0xF6
#define LOCK_BITS           0xFF                                                        // No Locks

// Place fuses in a special section (.fuse) in the .ELF output file
FUSES = {
    FUSE_BITS_LOW,              // .low
    FUSE_BITS_HIGH,             // .high
    FUSE_BITS_EXTENDED,         // .extended
};
//Place lockbits in a special section (.lock) in the .ELF output file
LOCKBITS = LOCK_BITS;


/******************************************************************************
*************** G L O B A L   V A R S   D E F I N I T I O N S *****************
******************************************************************************/

// Stores the current SYSTEM STATE. It's passed by reference to functions.
// Modified also in ISR.
volatile state_t system_state = SYSTEM_INTRO;

// Main loop execute flag: set every 1ms by an ISR. Used to synchronize the
// system states' loop execution every 1ms.
volatile uint8_t loop = FALSE;

// sleep mode (RTC state when in sleep modes)
// - RTC disabled: means oscillator stopped (POWER DOWN mode): This is only 
//      used when battery is connected first: RTC is not running
// - RTC enabled: means oscillator running, time is counting and ISRs are 
//      generated when in POWER SAVE mode.
volatile uint8_t sleep_mode = RTC_DISABLE;

// System reset:
uint8_t system_reset = FALSE;

/******************************************************************************
*************************** M A I N   P R O G R A M ***************************
******************************************************************************/

int main(void)
{
    /*
    * During normal execution, inside DISPLAY_TIME, if all three buttons are
    * pushed for DELAY3 milliseconds, execution jumps to RESET label. The
    * purpose is to restore the system to an initial default state, even
    * when the coin cell battery has been inserted. It forces the system to
    * go to sleep in PWR_DOWN mode, so that no RTC is enabled, thus keeping
    * the system halted until the next reconnection of the power adapter
    */
RESET:
    if(system_reset){
        sleep_mode = RTC_DISABLE;
        peripherals_disable(sleep_mode);
        BOOST_SET(DISABLE);
        while(EXT_PWR){
            // Toggle fast the onboard LED to indicate a reset condition
            led_blink(1,30);
        }
        system_reset = FALSE;
    }

    /* 
    * INITIALIZATION ----------------------------------------------------------
    * Power sources:
    *   - coin cell battery
    *   - 12V adapter
    * Once power is applied, system boots with default values. At this point, 
    * peripherals are initialized but not enabled (no clock applied to them)
    */
    boot();

    /*
    * Power source check:
    * Look for EXT_PWR pin. If there's an external power adapter connected,
    * Initialize RTC, enable Boost and all other peripherals. Run system.
    * If no voltage in EXT_PWR, it means that battery has been connected first.
    * In that case, do nothing and go to sleep.
    */
    if(EXT_PWR) {
        sleep_mode = RTC_ENABLE;
        system_state = SYSTEM_INTRO;
        peripherals_enable();
        led_blink(3, 40);
        uart_send_string_p(PSTR("\n\rFirmware Version: "));
        uart_send_string_p(PSTR(FIRMWARE_DATE));
        uart_send_string_p(PSTR("\n\r"));
    } else {
        sleep_mode = RTC_DISABLE;
        system_state = SYSTEM_SLEEP;
    }    

    /*
    * Production Test Enabled?
    * Use the ADC to sense the V_TST pin. If it is short-circuited, it means
    * that the production test must be launched, and a serial communication
    * link will be estabished with a PC using the UART.
    */
    if(system_state != SYSTEM_SLEEP){
        if(adc_factory_test_check())
            system_state = PRODUCTION_TEST;
    }

    /*
    * Voltages check:
    * The following voltages are checked to see wether the voltage ranges are 
    * properly met: V_HV, V_CTL_REG, V_IN
    * If any of these is out of range, inform the situation and jump to RESET.
    * Delay is necessary mainly to wait for boost output stabilization
    */
    if((system_state != SYSTEM_SLEEP) && (system_state != PRODUCTION_TEST)){
        //_delay_ms(1500);
        _delay_ms(2000);
        if(!adc_voltages_test()){
            uart_send_string_p(PSTR("\n\r*** System going down. Please disconnect ***"));  
            system_reset = TRUE;
            goto RESET;
        }
    }

    /*-------------------------------------------------------------------------
    ---------------- M A I N   I N F I N I T E   L O O P ----------------------
    -------------------------------------------------------------------------*/

    /*
    * Almost every case within the switch block includes an infinite loop
    * inside, which means that they handle all the system events inside of
    * every function. Whenever there's an event that requires a change in 
    * system state, the internal loop breaks and program execution returns to
    * this main loop, to then jump into the appropiate function.
    *
    * The two exceptions to this rule are
    * - SYSTEM_SLEEP: if the execution enters SYSTEM_SLEEP, the MCU will go
    * to sleep and execution will be stopped within that funciton
    * - SYSTEM_RESET: execution jumps to the beginning of main() to reset
    * all system, and goes to sleep later
    *
    * ISRs are serviced inside every system state function, at the end of the
    * loop execution, where no additional tasks are being executed. That way,
    * ISR execution won't overlap nor cause data corruption with other tasks.
    */
    while (TRUE)
    {
     	switch(system_state){

            // System Goes to Sleep and CPU is halted, except for the 
            // asynchronous timer running the RTC
            case SYSTEM_SLEEP:
                go_to_sleep(&system_state, sleep_mode); break;
            
            // First introductory animation
            case SYSTEM_INTRO:
                intro(&system_state); break;
            // Normal operation: tells the time, including some animations
            case DISPLAY_TIME:
                display_time(&system_state); break;
            // Configuration menu: navigates through all menu options
            case DISPLAY_MENU:
                display_menu(&system_state); break;
            // Config Option 1:
            case SET_TIME:
                set_time(&system_state); break;
            // Config Option 2:
            case SET_ALARM:
                set_alarm(&system_state); break;
            // Config Option 3:
            case SET_ALARM_ACTIVE:
                set_alarm_active(&system_state); break;
            // Config Option 4:
            case SET_HOUR_MODE:
                set_hour_mode(&system_state); break;
            // Config Option 5:
            case SET_TRANSITIONS:
                set_transitions(&system_state); break;
            // Config Option 6:
            case SET_ALARM_THEME:
                set_alarm_theme(&system_state); break;
            
            // If alarm is triggered: 
            case ALARM_TRIGGERED:
                alarm_triggered(&system_state); break;
            
            // User-accessible test sequence: It tests all the tubes' digits,
            // the RTC 1Hz sync signal, the individual RGB LEDs and the buzzer.
            case USR_TEST:
                usr_test(&system_state); break;
            case PRODUCTION_TEST:
                production_test(&system_state); break;

            // Jump to a reset state
            case SYSTEM_RESET:
                goto RESET; break;
            default:
                system_state = DISPLAY_TIME; break;
        }
    } /* While Loop */

    return 0;
} /* Main Function */

/******************************************************************************
*******************************************************************************

                    I N T E R R U P T   H A N D L E R S

*******************************************************************************
******************************************************************************/

// ASCII table for numbers
static const char bcd_to_ascii[] PROGMEM = {'0','1','2','3','4','5','6','7','8','9'};

/*-----------------------------------------------------------------------------
                      R E A L   T I M E   C O U N T E R
-----------------------------------------------------------------------------*/
/*
* TIMER 2 interrupts are Asynchronous!, meaning that the peripheral uses the 
* external 32.768KHz watch crystal as clock source. Interrupts are generated 
* once every second. 
* - time structure is updated in every execution
* - alarm is checked to see if it matches
* - hour is reported via uart every second (provided that power adapter is 
*   plugged in)
*/
ISR(TIMER2_OVF_vect){

    time.update = TRUE;

    if(system_state != PRODUCTION_TEST){

        // update time variables
        time.sec++;
        if(time.sec == 60){
            time.sec = 0;
            time.min++;
            if(time.min == 60){
                time.min = 0;
                time.hour++;
                // different increments for 12/24h modes
                if(time.hour_mode == MODE_12H){
                    if(time.hour == 12){
                        // toggle AM/PM
                        if(time.day_period == PERIOD_AM) time.day_period = PERIOD_PM;
                        else if(time.day_period == PERIOD_PM) time.day_period = PERIOD_AM;
                    } else if(time.hour == 13){
                        // reset hours
                        time.hour = 1;
                    }
                } else if(time.hour_mode == MODE_24H){
                    if(time.hour == 12){
                        time.day_period = PERIOD_PM;
                    } else if(time.hour == 24){
                        time.day_period = PERIOD_AM;
                        time.hour = 0;
                    }
                }
            }
        }
        
        // update time BCD variables
        time.s_tens = time.sec / 10;
        time.s_units = time.sec % 10;
        time.m_tens = time.min / 10;
        time.m_units = time.min % 10;
        time.h_tens = time.hour / 10;
        time.h_units = time.hour % 10;

        // Check alarm match. If true, jump directly to the ALARM_TRIGGERED state,
        // no matter what the clock is doing
        if(check_alarm()) system_state = ALARM_TRIGGERED;

        // if power adapter is connected (if not, the MCU is powered be running 
        // with the coin cell battery):
        // - toggle LED
        // - send time with UART
        // if not connected, do not report time nor toggle led.
        if(EXT_PWR) {
            RTC_SIGNAL_TOGGLE();
            char string[9];
            string[0] = (char)pgm_read_byte(&bcd_to_ascii[time.h_tens]);
            string[1] = (char)pgm_read_byte(&bcd_to_ascii[time.h_units]);
            string[2] = ':';
            string[3] = (char)pgm_read_byte(&bcd_to_ascii[time.m_tens]);
            string[4] = (char)pgm_read_byte(&bcd_to_ascii[time.m_units]);
            string[5] = ':';
            string[6] = (char)pgm_read_byte(&bcd_to_ascii[time.s_tens]);
            string[7] = (char)pgm_read_byte(&bcd_to_ascii[time.s_units]);
            string[8] = '\0';
            uart_send_string(string);
            uart_send_string("\n\r");
        } else {
            RTC_SIGNAL_SET(LOW);
        }   
    }
}

/*-----------------------------------------------------------------------------
                    G E N E R A L   T I M E R   C O U N T E R
-----------------------------------------------------------------------------*/
/*
* TIMER 3 is used as a general purpose counter. Interrupts are generated every
* 1ms and this time base is used for multiple purposes:
* - loop flag is set in every execution
* - Nixie tubes multiplexing routine is handled based on an internal counter
* - Nixie tubes fading routine is handled based on an internal counter
*/
ISR(TIMER3_COMPA_vect){

    static uint8_t n_tube = 1;   // determines which tube to light up (1, 2, 3 or 4)
    static uint8_t n_fade = 5;      // 4 Fading levels (1 to 4)
                                    // 0: fully off; 5: fully on
    static uint16_t cnt = 0;        // general purpose counter

    // execute main loop every 1ms.
    loop = TRUE;

    if(system_state != PRODUCTION_TEST){
        // multiplex tubes' anode every 5ms. Independent of fading level
        if(!(cnt % 5)){
            // change tube selection
            n_tube++;
            if(n_tube >= 4) n_tube = 0;
            // enable tube anode
            set_tube(n_tube);
        }
        
        // to better perform digits' fading, the digits (cathodes) are updated 
        // every 1ms:
        if(display.set){
            if(n_fade <= display.fade_level[n_tube]){
                if(n_tube == TUBE_A) set_digit(display.d1);
                else if(n_tube == TUBE_B) set_digit(display.d2);
                else if(n_tube == TUBE_C) set_digit(display.d3);
                else if(n_tube == TUBE_D) set_digit(display.d4);
            } else {
                set_digit(BLANK);
            }
        } else {
            set_digit(BLANK);
        }

        // general counter reset
        cnt++;
        if(cnt == 1000) cnt = 0;
        // fade level counter
        n_fade++;
        if(n_fade > 5) n_fade = 1;
    }
}

/*-----------------------------------------------------------------------------
                    E X T E R N A L   I N T E R R U P T S
-----------------------------------------------------------------------------*/
/*
* EXTERNAL INTERRUPTS are active for two sources: buttons and external power
* adapter connection.
* - When buttons are pressed, btnXYZ.query flag is set and the buttons are
*   polled to determine its state.
* - When EXT_PWR pin triggers the ISR, the power adapter was either removed
*   or plugged. Thus, check EXT_PWR level and decide whether going to sleep
*   or keep normal execution.
*/

/*===========================================================================*/
/* 
* buttons     
* BTN_X       - PB5 - PCINT13 | -> PCI1
* BTN_Y       - PB6 - PCINT14 | -> PCI1
* BTN_Z       - PB7 - PCINT15 | -> PCI1 
*/
ISR(PCINT1_vect)
{
    if((!(btnX.check)()) && (!(btnX.lock))){
        btnX.query = TRUE;
    } else if((!(btnY.check)()) && (!(btnY.lock))){
        btnY.query = TRUE;
    } else if((!(btnZ.check)()) && (!(btnZ.lock))){
        btnZ.query = TRUE;
    }
}

/*===========================================================================*/
/* 
* External power
* if external power is removed, enter in power save mode 
* EXT_PWR     - PC2 - PCINT18  | -> PCI2
*/
ISR(PCINT2_vect)
{
    if(!EXT_PWR){
        // Boost is automatically powered off (12V removed)
        RTC_SIGNAL_SET(LOW);          // Dont use RTC LED
        system_state = SYSTEM_SLEEP;  // GO TO SLEEP !!!
    }
}

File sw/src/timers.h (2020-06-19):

/**
 * @file timers.h
 * @brief Timer counter configurations
 *
 * @author Jose Logreira
 * @date 15.05.2018
 *
 */

#ifndef TIMERS_H
#define TIMERS_H

/******************************************************************************
*******************	I N C L U D E   D E P E N D E N C I E S	*******************
******************************************************************************/

#include "config.h"

#include <stdint.h>

/******************************************************************************
***************** S T R U C T U R E   D E C L A R A T I O N S *****************
******************************************************************************/

typedef volatile struct {
    uint8_t mode;
    uint8_t d1;
    uint8_t d2;
    uint8_t d3;
    uint8_t d4;
    uint8_t set;
    uint8_t fade_level[4];
} display_s;

extern display_s display;

/******************************************************************************
******************* C O N S T A N T   D E F I N I T I O N S *******************
******************************************************************************/

// LED Register Counters 
#define R_LED			OCR0A
#define G_LED			OCR0B
#define B_LED			OCR1A

/******************************************************************************
******************** F U N C T I O N   P R O T O T Y P E S ********************
******************************************************************************/

void display_init(void);

void timer_rtc_set(uint8_t state);

void timer_base_init(void);
void timer_buzzer_init(void);
void timer_leds_init(void);

void timer_base_set(uint8_t state);
void timer_buzzer_set(uint8_t state, uint16_t note);
void timer_leds_set(uint8_t state, uint8_t r, uint8_t g, uint8_t b);

#endif	/* TIMERS_H */

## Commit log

2020-06-10 First round of code refactoring
    Some decissions: Won't change the general code structure.
    It'll remain as-is just to have it as a good future reference.
    Besides, the code is pretty well documented.
    [adc.c, buzzer.c, debug.c]
2020-06-13 By documenting the code base it's notorious that the main loop code is not clear. It's best to include the sei/cli code and buttons routines inside every display state.
    So let's do it from here
2020-06-16 Added documentation, and some code refactoring for buzzer module
    [buzzer.c, main.c, sleep.c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]
2020-06-19 Corrected .h files dependencies
    [adc.c, buzzer.c, debug.c]
2020-07-01 Added documentation. Added hw designs
    [BOM.ods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]
